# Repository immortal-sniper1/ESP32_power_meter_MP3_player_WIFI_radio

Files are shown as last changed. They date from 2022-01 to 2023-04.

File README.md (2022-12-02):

# PCB_test_project_01
 First ESP32 pcb project, it will have power meters( 24V 3A, 5V 0.5A, and self consumption), uSD card, WIFI/BT and the ability to play back MP3/audio file.     
 Also it will feature a power usage meter. It can also be powered from a 18650 Li ion cell, if the USB is alsoo pluged in the cell will start chargeing.
 The chargeing current is limited by the chargeing IC useing a potenciometer as the input. If the red LED is on then the cell is cahrgeing and if the green
 LED is on then the cell is fully charged.
 NOTE: the voltage levels are set by the ICs and it is : 4.2V as charged state and 3V as discharged.
 If the cel voltage reaches 3V or lower then a circuit will activate and disconect the cell from the system so that it will not overdischarge.
 
 V1 is made with ESP32-MINI and that is super hard to hand assemble so V2+ wil use the VROOM

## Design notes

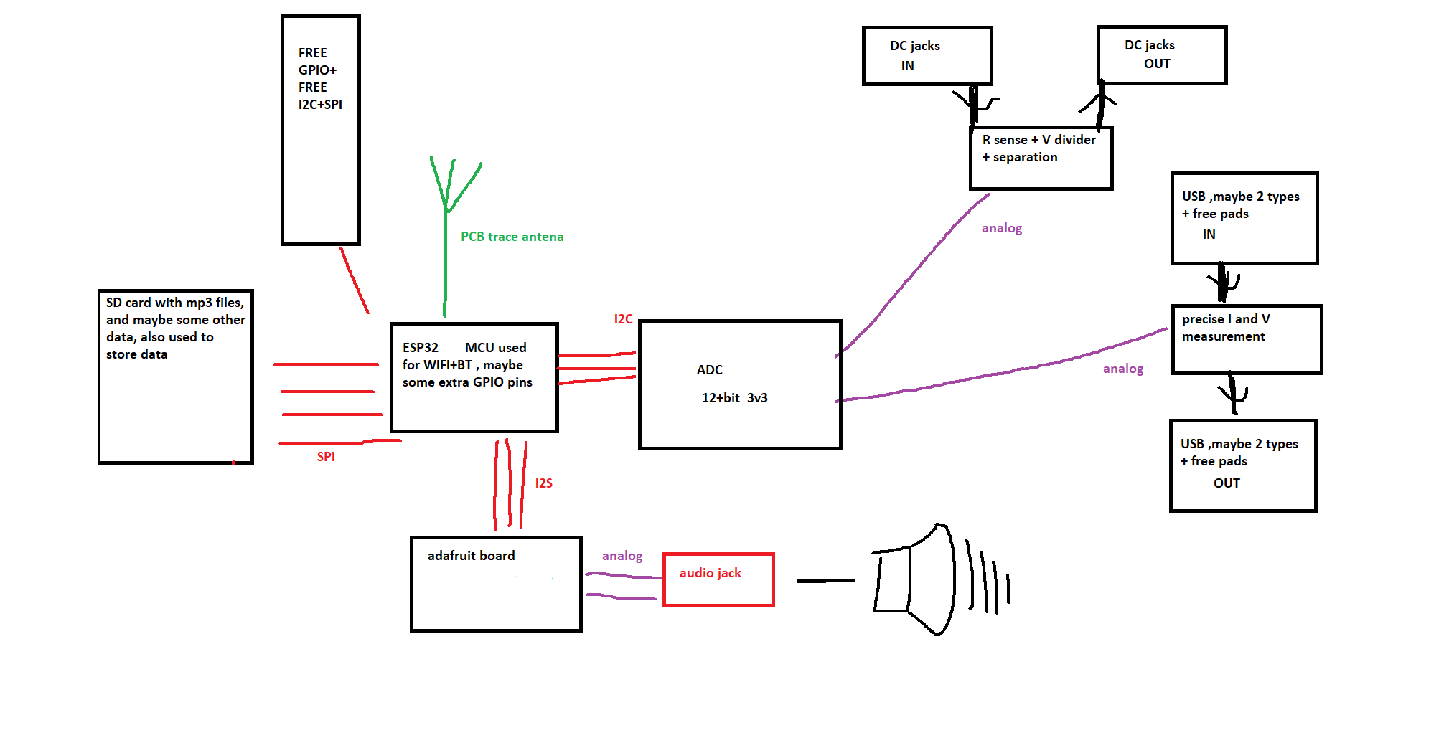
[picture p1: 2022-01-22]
ESP32_power_meter_MP3_player_WIFI_radio_V2/concept.png

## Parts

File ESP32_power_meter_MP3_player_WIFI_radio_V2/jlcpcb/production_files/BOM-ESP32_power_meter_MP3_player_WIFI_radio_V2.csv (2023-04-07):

Comment | Designator | Footprint | LCSC
100n | C13,C14,C15,C18,C21,C30 | C_0603_1608Metric_Pad1.08x0.95mm_HandSolder | C14663
100n | C10,C12,C16,C17,C19,C2,C20,C24,C3,C31,C6,C8 | C_0603_1608Metric_Pad1.08x0.95mm_HandSolder | C1623
1k | R1,R31,R34,R39,R41 | R_0603_1608Metric_Pad0.98x0.95mm_HandSolder | C21190
LED_Small | D5 | LED_0603_1608Metric_Pad1.05x0.95mm_HandSolder | C2286
0 | R49,R50 | R_0603_1608Metric_Pad0.98x0.95mm_HandSolder | C22936
330 | R10,R11,R12 | R_0603_1608Metric_Pad0.98x0.95mm_HandSolder | C23025
4k7 | R9 | R_0603_1608Metric_Pad0.98x0.95mm_HandSolder | C23162
91k | RR1 | R_0805_2012Metric_Pad1.20x1.40mm_HandSolder | C23265
100k | R16,R17,R20,R26,R32,R36 | R_0603_1608Metric_Pad0.98x0.95mm_HandSolder | C25803
10k | R13,R14,R15,R18,R19,R2,R21,R22,R23,R24,R25,R27,R3,R33,R35,R37,R38,R4,R40,R43,R44,R45,R46,R48,R5,R51,R6,R7,R8 | R_0603_1608Metric | C25804
GPIO_RESET | SW1,SW2,SW3 | PTS526SK15SMTR2LFS | C318884
20k | RR2 | R_0805_2012Metric_Pad1.20x1.40mm_HandSolder | C4184
10u | C1,C22,C23,C25,C26,C28,C29,C4,C5,C7,C9 | C_0805_2012Metric | C45783
LM324 | U6 | SOIC-14_3.9x8.7mm_P1.27mm | C71035
Green | D1,D2,D3,D4,D6 | LED_0603_1608Metric_Pad1.05x0.95mm_HandSolder | C72043
SRV05-4 | U5 | SOT-23-6 | C85364
FerriteBead_Small | FB2 | R_0603_1608Metric_Pad0.98x0.95mm_HandSolder
Conn_01x03 | J12 | SCREWTERMINAL-5MM-3
I2C | J16 | PinHeader_1x04_P2.54mm_Vertical
HI1806T600R-10 | FB1 | BEADC4516X185N
APX810S05 | U8 | SOT-23
LM4040DBZ-3 | U1 | SOT-23
Conn_02x10_Odd_Even | J14 | PinHeader_2x10_P2.54mm_Vertical
Conn_01x02 | J10 | TestPoint_2Pads_Pitch5.08mm_Drill1.3mm
DIO6012BCST6 | U9 | SOT-23-6_Handsoldering
22p optional | C27 | C_0603_1608Metric_Pad1.08x0.95mm_HandSolder
ESP32-S3-WROOM-1 | U4 | ESP32-S3-WROOM-1
Conn_01x02 | J13 | PinHeader_1x02_P2.54mm_Vertical
Barrel_Jack_Switch | J5 | DC plug jack 5.5-2.5mm
1.5 A | F1 | Fuse_1812_4532Metric
30m | R29 | R_0805_2012Metric
MEM2051-00-195-00-A | J2 | MEM20510019500A
INA2181A4QDGSRQ1 | IC2 | SOP50P490X110-10N
DS01C-254-S-08BE | S1 | DS01C254S08BE
DMG9933USD-13 | Q2 | SOIC127P600X175-8N
Conn_01x03 | J9 | SCREWTERMINAL-5MM-3
Barrel_Jack_Switch | J7 | BarrelJack_Wuerth_6941xx301002
DNP | C11 | C_0603_1608Metric_Pad1.08x0.95mm_HandSolder
XRA1203IG24TR-F | IC1 | SOP65P640X120-24N
USB_A | J11 | USB_A_Molex_67643_Horizontal
1Meg | R30 | R_0603_1608Metric_Pad0.98x0.95mm_HandSolder
L_Small | L2 | L_1206_3216Metric
USB_A | J3 | USB_A_Molex_67643_Horizontal
5m | R42 | R_0612_1632Metric_Pad1.18x3.40mm_HandSolder
Jumper_3_Open | JP1 | PinHeader_1x03_P2.54mm_Vertical
Adafruit_MAX98357 | U3 | Adafruit MAX98357 I2S Class-D Mono
EG1224 SPDT switch | S2 | EG1224
NRH3012T2R2MN 2,2uH | L1 | NRH3012T220MNV
USB_A | J8 | USB_A_Molex_67643_Horizontal
Conn_01x06 | J4 | PinHeader_1x06_P2.54mm_Vertical
R_Potentiometer | RV1 | Potentiometer_Bourns_3386F_Vertical
STX-3120-5B | J1 | STX31205B
MCP73834T-FCI_UN | IC4 | SOP50P490X110-10N
MCP3208 | U2 | SOIC-16_3.9x9.9mm_P1.27mm
1.5 A | F2 | Fuse_1812_4532Metric
5m | R28 | R_0612_1632Metric_Pad1.18x3.40mm_HandSolder
I2C | J15 | PinHeader_1x04_P2.54mm_Vertical
Conn_01x02 | J6 | TestPoint_2Pads_Pitch5.08mm_Drill1.3mm
AP2112M-3.3TRG1 | IC3 | SOIC127P600X170-8N
D_Shockley | D7 | D_DO-15_P5.08mm_Vertical_AnodeUp
1043 | U7 | 1043

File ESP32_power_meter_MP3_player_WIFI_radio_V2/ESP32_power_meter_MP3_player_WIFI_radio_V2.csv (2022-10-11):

picked | Ref | Qnty | Value | Cmp name | Footprint
 | C1, C3, C8, C26, | 4 | 10u | C_Small | Capacitor_SMD:C_0603_1608Metric_Pad1.08x0.95mm_HandSolder
 | C2, C9, C11, C13, C15, | 5 | 1u | C_Small | Capacitor_SMD:C_0603_1608Metric_Pad1.08x0.95mm_HandSolder
 | C4, C5, C6, C7, C12, C14, C23, | 7 | 100n | C_Small | Capacitor_SMD:C_0603_1608Metric_Pad1.08x0.95mm_HandSolder
 | C10, | 1 | 0.1u | C_Small | Capacitor_SMD:C_0603_1608Metric_Pad1.08x0.95mm_HandSolder
 | C16, | 1 | 4.7u | C_Small | Capacitor_SMD:C_0603_1608Metric_Pad1.08x0.95mm_HandSolder
 | C17, C18, | 2 | 1u | C_Small | Capacitor_SMD:C_0805_2012Metric_Pad1.18x1.45mm_HandSolder
 | C19, | 1 | 22u | C_Small | Capacitor_THT:CP_Radial_D5.0mm_P2.00mm
 | C20, | 1 | 22p optional | C_Small | Capacitor_SMD:C_0603_1608Metric_Pad1.08x0.95mm_HandSolder
 | C21, C22, C24, C25, | 4 | 10u | C_Small | Capacitor_SMD:C_0805_2012Metric
 | D1, D5, D6, D7, D8, D9, | 6 | LED_Small Green | LED_Small | LED_SMD:LED_0603_1608Metric_Pad1.05x0.95mm_HandSolder
 | D2, D3, | 2 | LED_Small | LED_Small | LED_SMD:LED_0603_1608Metric_Pad1.05x0.95mm_HandSolder
 | D4, | 1 | D_Shockley | D_Shockley | Diode_THT:D_DO-15_P5.08mm_Vertical_AnodeUp
 | F1, F2, | 2 | 1.5 A | Fuse | Fuse:Fuse_0603_1608Metric_Pad1.05x0.95mm_HandSolder
 | FB1, | 1 | HI1806T600R-10 | HI1806T600R-10 | SamacSys_Parts:BEADC4516X185N
 | FB2, | 1 | FerriteBead_Small | FerriteBead_Small | Resistor_SMD:R_0402_1005Metric_Pad0.72x0.64mm_HandSolder
 | IC1, | 1 | XRA1203IG24TR-F | XRA1203IG24TR-F | SamacSys_Parts:SOP65P640X120-24N
 | IC2, | 1 | INA2181A4QDGSRQ1 | INA2181A4QDGSRQ1 | SOP50P490X110-10N
 | IC3, | 1 | MCP73834T-FCI_UN | MCP73834T-FCI_UN | SamacSys_Parts:SOP50P490X110-10N
 | IC4, | 1 | AP2112M-3.3TRG1 | AP2112M-3.3TRG1 | SamacSys_Parts:SOIC127P600X170-8N
 | J1, | 1 | STX-3120-5B | STX-3120-5B | SamacSys_Parts:STX31205B
 | J2, | 1 | SS-52100-001 | SS-52100-001 | SamacSys_Parts:SS52100001
 | J3, | 1 | MEM2051-00-195-00-A | MEM2051-00-195-00-A | SamacSys_Parts:MEM20510019500A
 | J4, | 1 | Barrel_Jack_Switch | Barrel_Jack_Switch | Z_mycustom_footprint_lib:DC plug jack 5.5-2.5mm
 | J5, | 1 | Barrel_Jack_Switch | Barrel_Jack_Switch | Connector_BarrelJack:BarrelJack_Wuerth_6941xx301002
 | J6, J7, | 2 | Conn_01x03 | Conn_01x03 | Connectors:SCREWTERMINAL-5MM-3
 | J8, | 1 | Conn_01x06 | Conn_01x06 | Connector_PinHeader_2.54mm:PinHeader_1x06_P2.54mm_Vertical
 | J9, | 1 | USB_A | USB_A | Connector_USB:USB_A_Molex_67643_Horizontal
 | J10, | 1 | 10033527-N3112MLF | 10033527-N3112MLF | SamacSys_Parts:10033527N3112MLF
 | J11, J12, | 2 | Conn_01x02 | Conn_01x02 | TestPoint:TestPoint_2Pads_Pitch5.08mm_Drill1.3mm
 | J13, | 1 | Conn_01x02 | Conn_01x02 | Connector_PinHeader_2.54mm:PinHeader_1x02_P2.54mm_Vertical
 | JP1, | 1 | Jumper_2_Bridged | Jumper_2_Bridged | Jumper:SolderJumper-2_P1.3mm_Bridged_RoundedPad1.0x1.5mm
 | JP2, | 1 | Jumper_3_Open | Jumper_3_Open | Connector_PinHeader_2.54mm:PinHeader_1x03_P2.54mm_Vertical
 | L1, | 1 | NRH3012T2R2MN 2,2uH | NRH3012T2R2MN | SamacSys_Parts:NRH3012T220MNV
 | Q1, | 1 | DMG9933USD-13 | DMG9933USD-13 | SamacSys_Parts:SOIC127P600X175-8N
 | R1, R24, R25, | 3 | 1k | R_Small | Resistor_SMD:R_0603_1608Metric_Pad0.98x0.95mm_HandSolder
 | R2, R4, R5, R6, R7, R8, R9, R10, R11, R12, R13, R14, R15, R16, R17, R18, R19, R21, R22, R23, R28, R33, R34, R38, R39, R40, | 26 | 10k | R | Resistor_SMD:R_0603_1608Metric_Pad0.98x0.95mm_HandSolder
 | R3, | 1 | 20k | R | Resistor_SMD:R_0603_1608Metric_Pad0.98x0.95mm_HandSolder
 | R20, | 1 | 4.7k | R | Resistor_SMD:R_0805_2012Metric
 | R26, R27, R29, | 3 | 100k | R_Small | Resistor_SMD:R_0603_1608Metric_Pad0.98x0.95mm_HandSolder
 | R30, R44, R45, R46, R47, | 5 | 330 | R | Resistor_SMD:R_0603_1608Metric_Pad0.98x0.95mm_HandSolder
 | R31, R41, | 2 | 5m | R | Resistor_SMD:R_0612_1632Metric_Pad1.18x3.40mm_HandSolder
 | R32, R42, R43, | 3 | 1Meg | R_Small | Resistor_SMD:R_0603_1608Metric_Pad0.98x0.95mm_HandSolder
 | R35, | 1 | 30m | R | Resistor_SMD:R_0402_1005Metric_Pad0.72x0.64mm_HandSolder
 | R36, R37, | 2 | 470 | R_Small | Resistor_SMD:R_0603_1608Metric_Pad0.98x0.95mm_HandSolder
 | RR1, | 1 | 91k | R_Small | Resistor_SMD:R_0805_2012Metric_Pad1.20x1.40mm_HandSolder
 | RR2, | 1 | 20k | R_Small | Resistor_SMD:R_0805_2012Metric_Pad1.20x1.40mm_HandSolder
 | RV1, | 1 | R_Potentiometer | R_Potentiometer | Potentiometer_THT:Potentiometer_Bourns_3386F_Vertical
 | S1, S2, | 2 | DS01C-254-S-08BE | DS01C-254-S-08BE | SamacSys_Parts:DS01C254S08BE
 | S3, | 1 | EG1224 SPDT switch | EG1224 | SamacSys_Parts:EG1224
 | SW1, | 1 | SW_SPST | SW_SPST | SamacSys_Parts:PTS526SM15SMTR2LFS
 | TP1, TP2, TP3, | 3 | TestPoint | TestPoint | TestPoint:TestPoint_Pad_1.0x1.0mm
 | U1, | 1 | ESP32-C3-MINI-1 | ESP32-C3-MINI-1 | Espressif:ESP32-C3-MINI-1_Hand-Soldering
 | U2, | 1 | LM4040DBZ-3 | LM4040DBZ-3 | Package_TO_SOT_SMD:SOT-23
 | U3, | 1 | MCP3208 | MCP3208 | Package_SO:SOIC-16_3.9x9.9mm_P1.27mm
 | U4, | 1 | Adafruit_MAX98357 | Adafruit_MAX98357 | Z_mycustom_footprint_lib:Adafruit MAX98357 I2S Class-D Mono
 | U5, | 1 | D1213A-02SM | D1213A-02SM | Package_TO_SOT_SMD:SOT-23-5
 | U6, | 1 | LM324A | LM324A | Package_SO:SOIC-14_3.9x8.7mm_P1.27mm
 | U7, | 1 | 1043 | 1043 | SamacSys_Parts:1043
 | U8, | 1 | APX810S05 | APX810S05 | Package_TO_SOT_SMD:SOT-23
 | U10, | 1 | DIO6012BCST6 | DIO6012BCST6 | Package_TO_SOT_SMD:SOT-23-6_Handsoldering

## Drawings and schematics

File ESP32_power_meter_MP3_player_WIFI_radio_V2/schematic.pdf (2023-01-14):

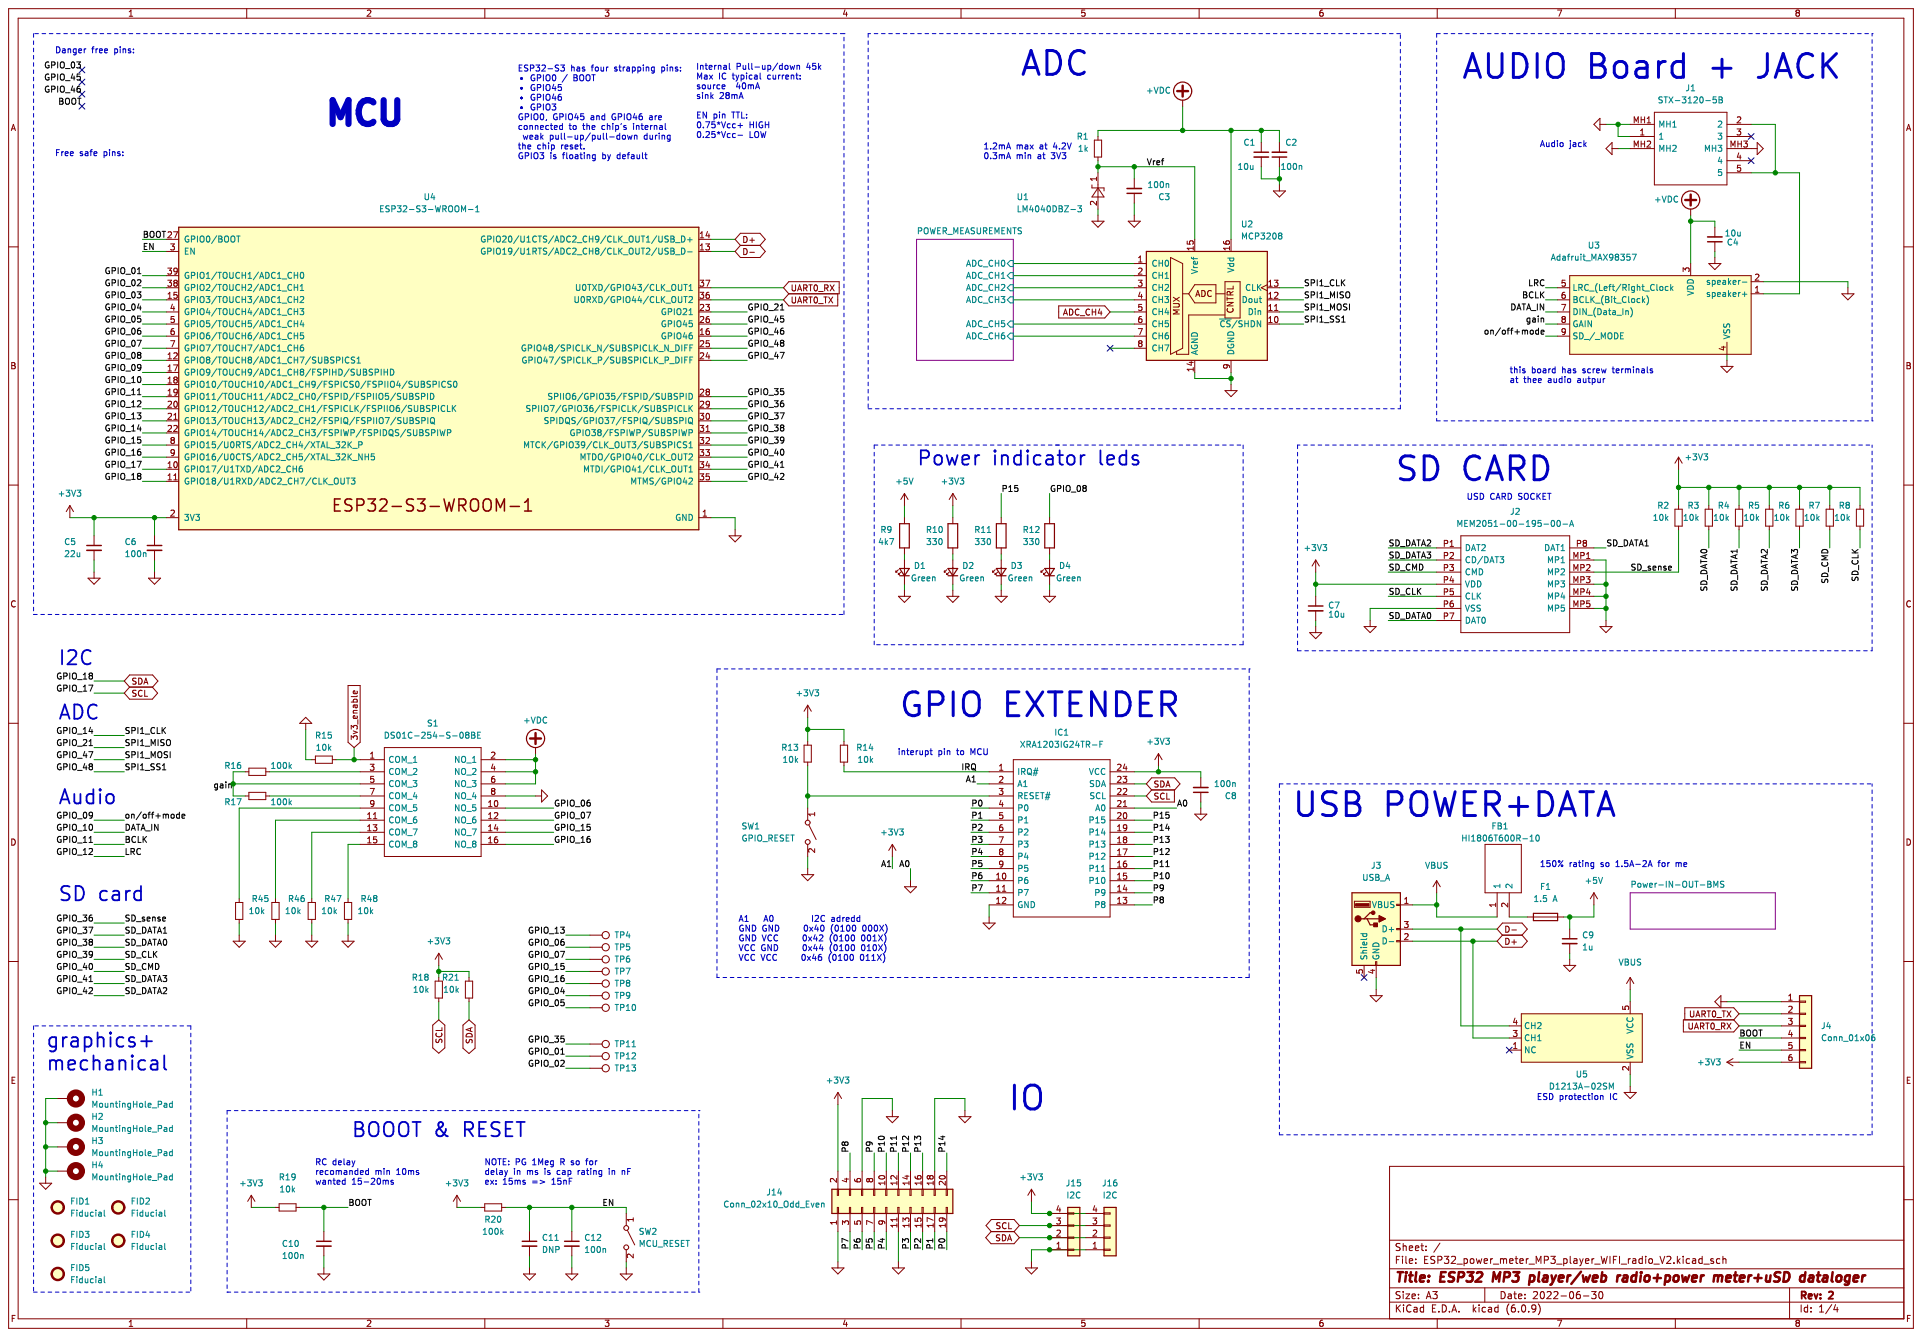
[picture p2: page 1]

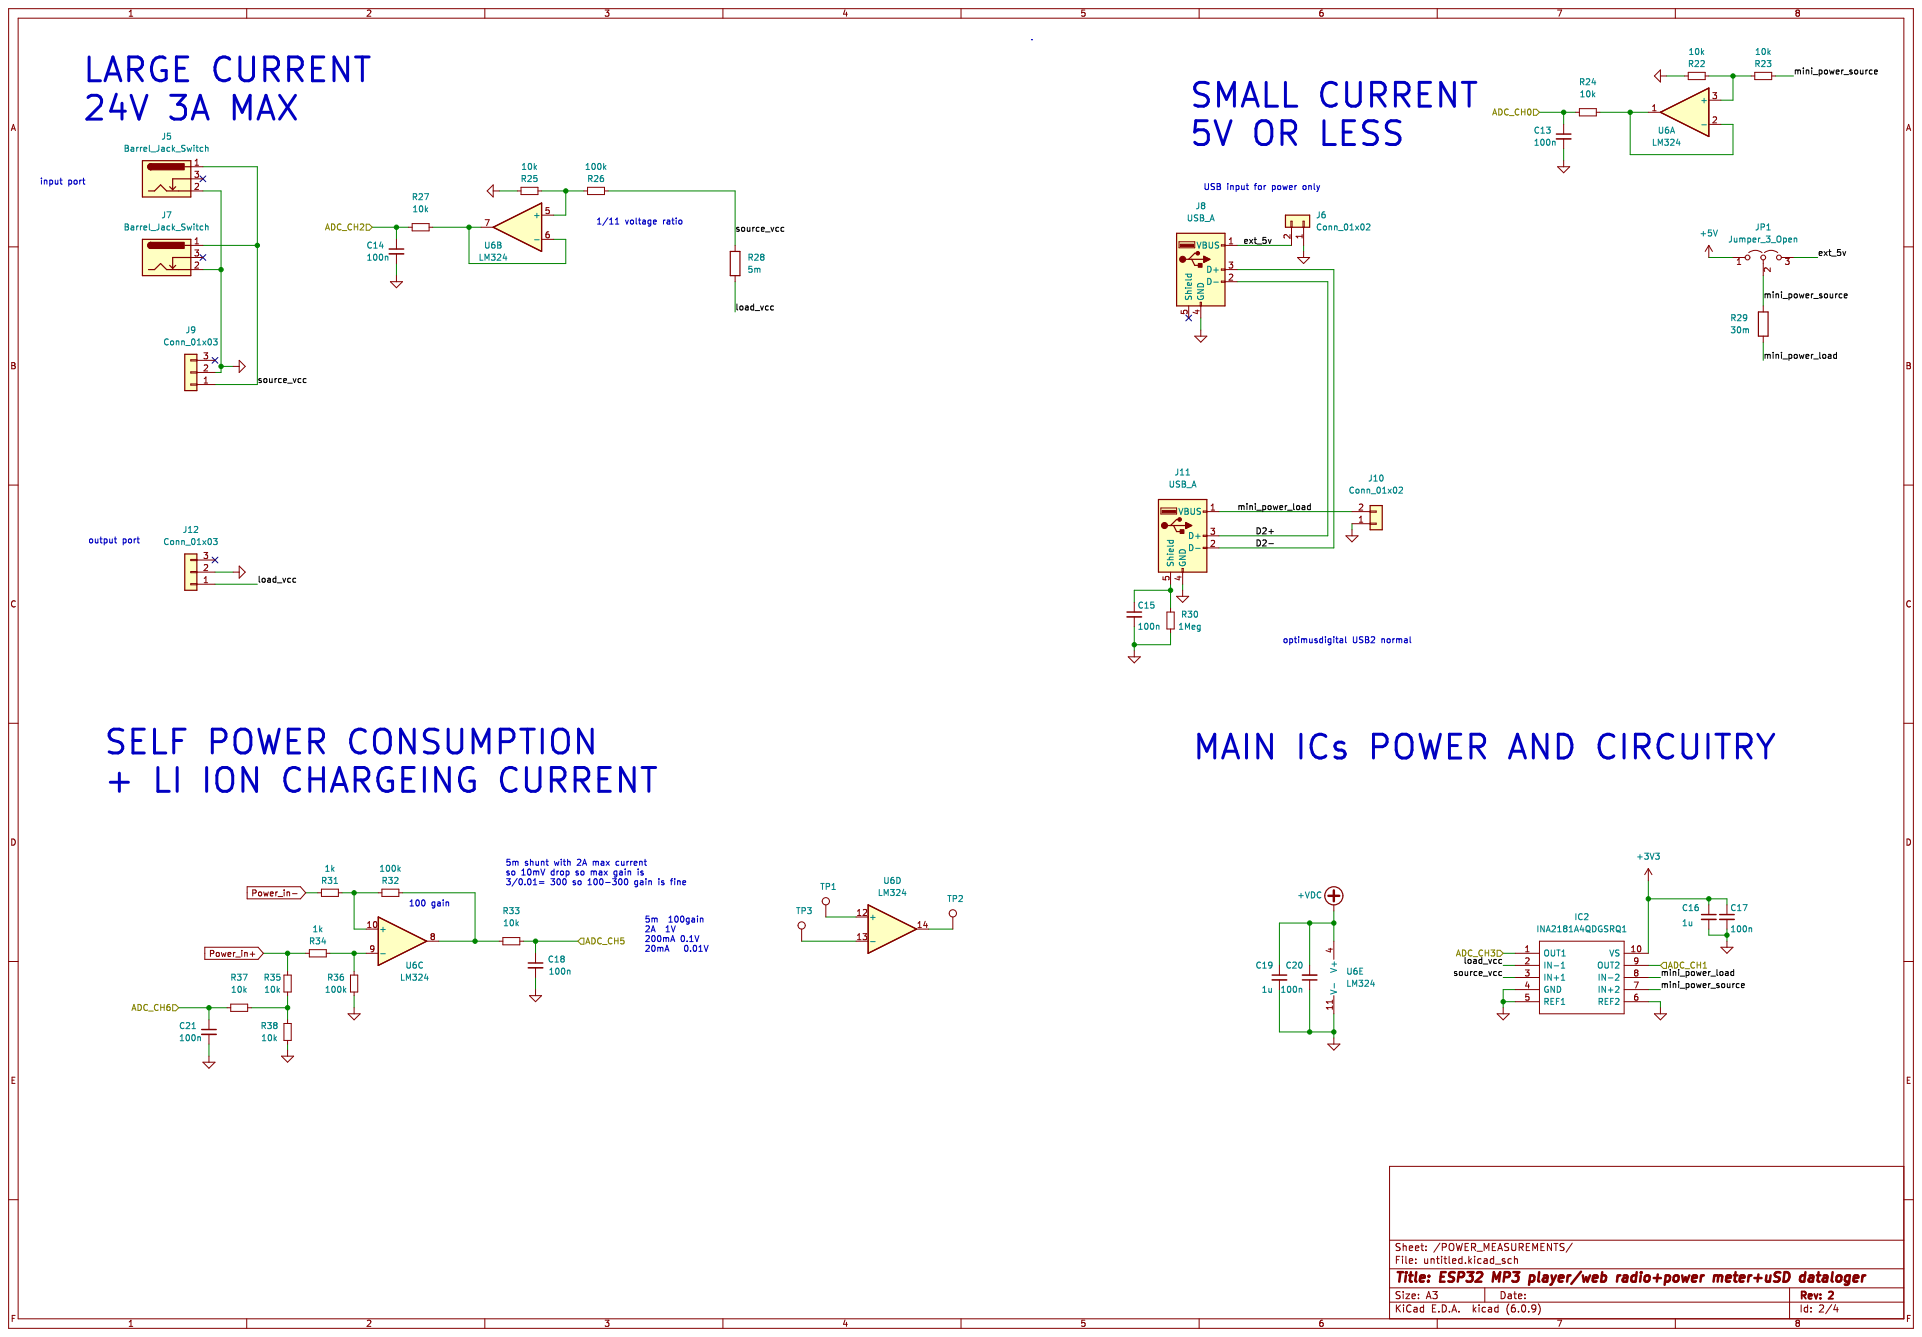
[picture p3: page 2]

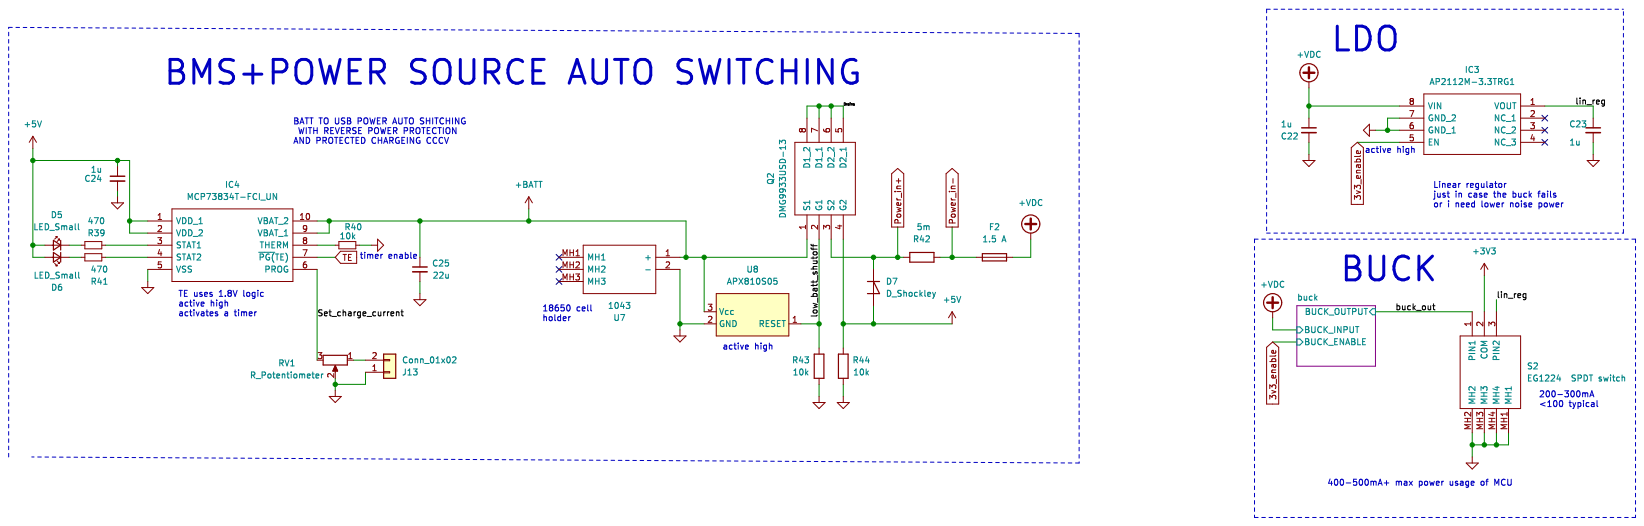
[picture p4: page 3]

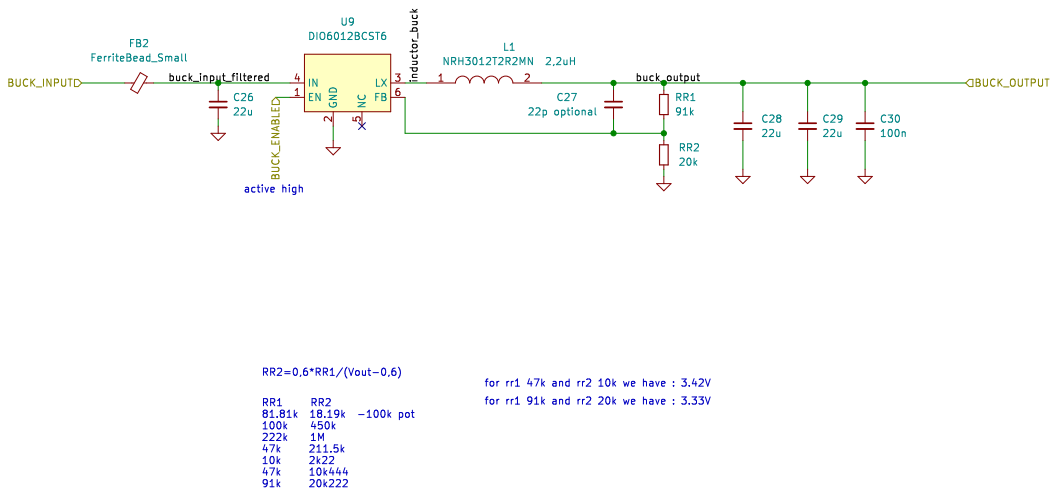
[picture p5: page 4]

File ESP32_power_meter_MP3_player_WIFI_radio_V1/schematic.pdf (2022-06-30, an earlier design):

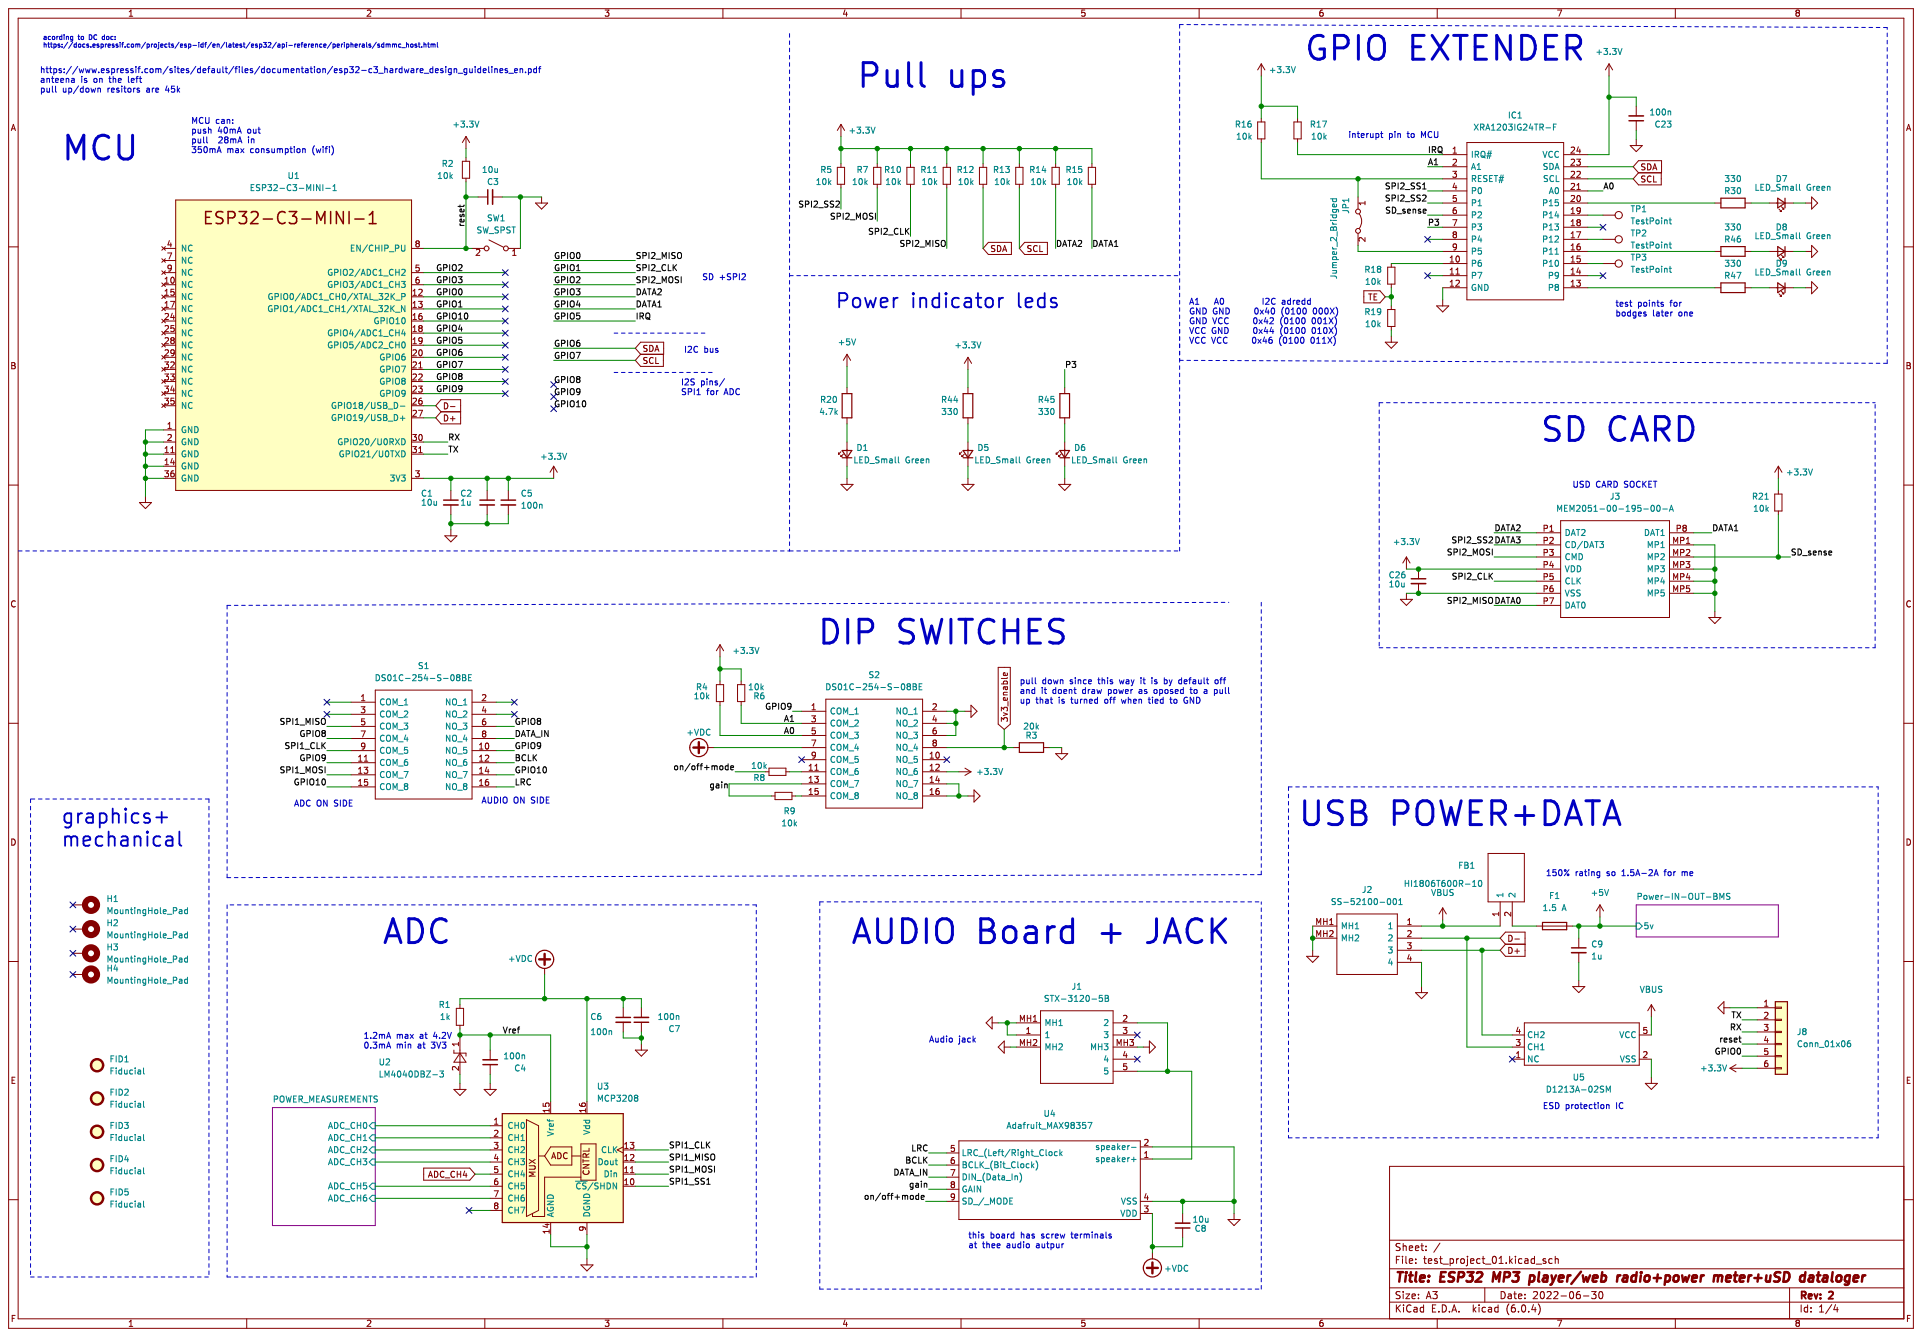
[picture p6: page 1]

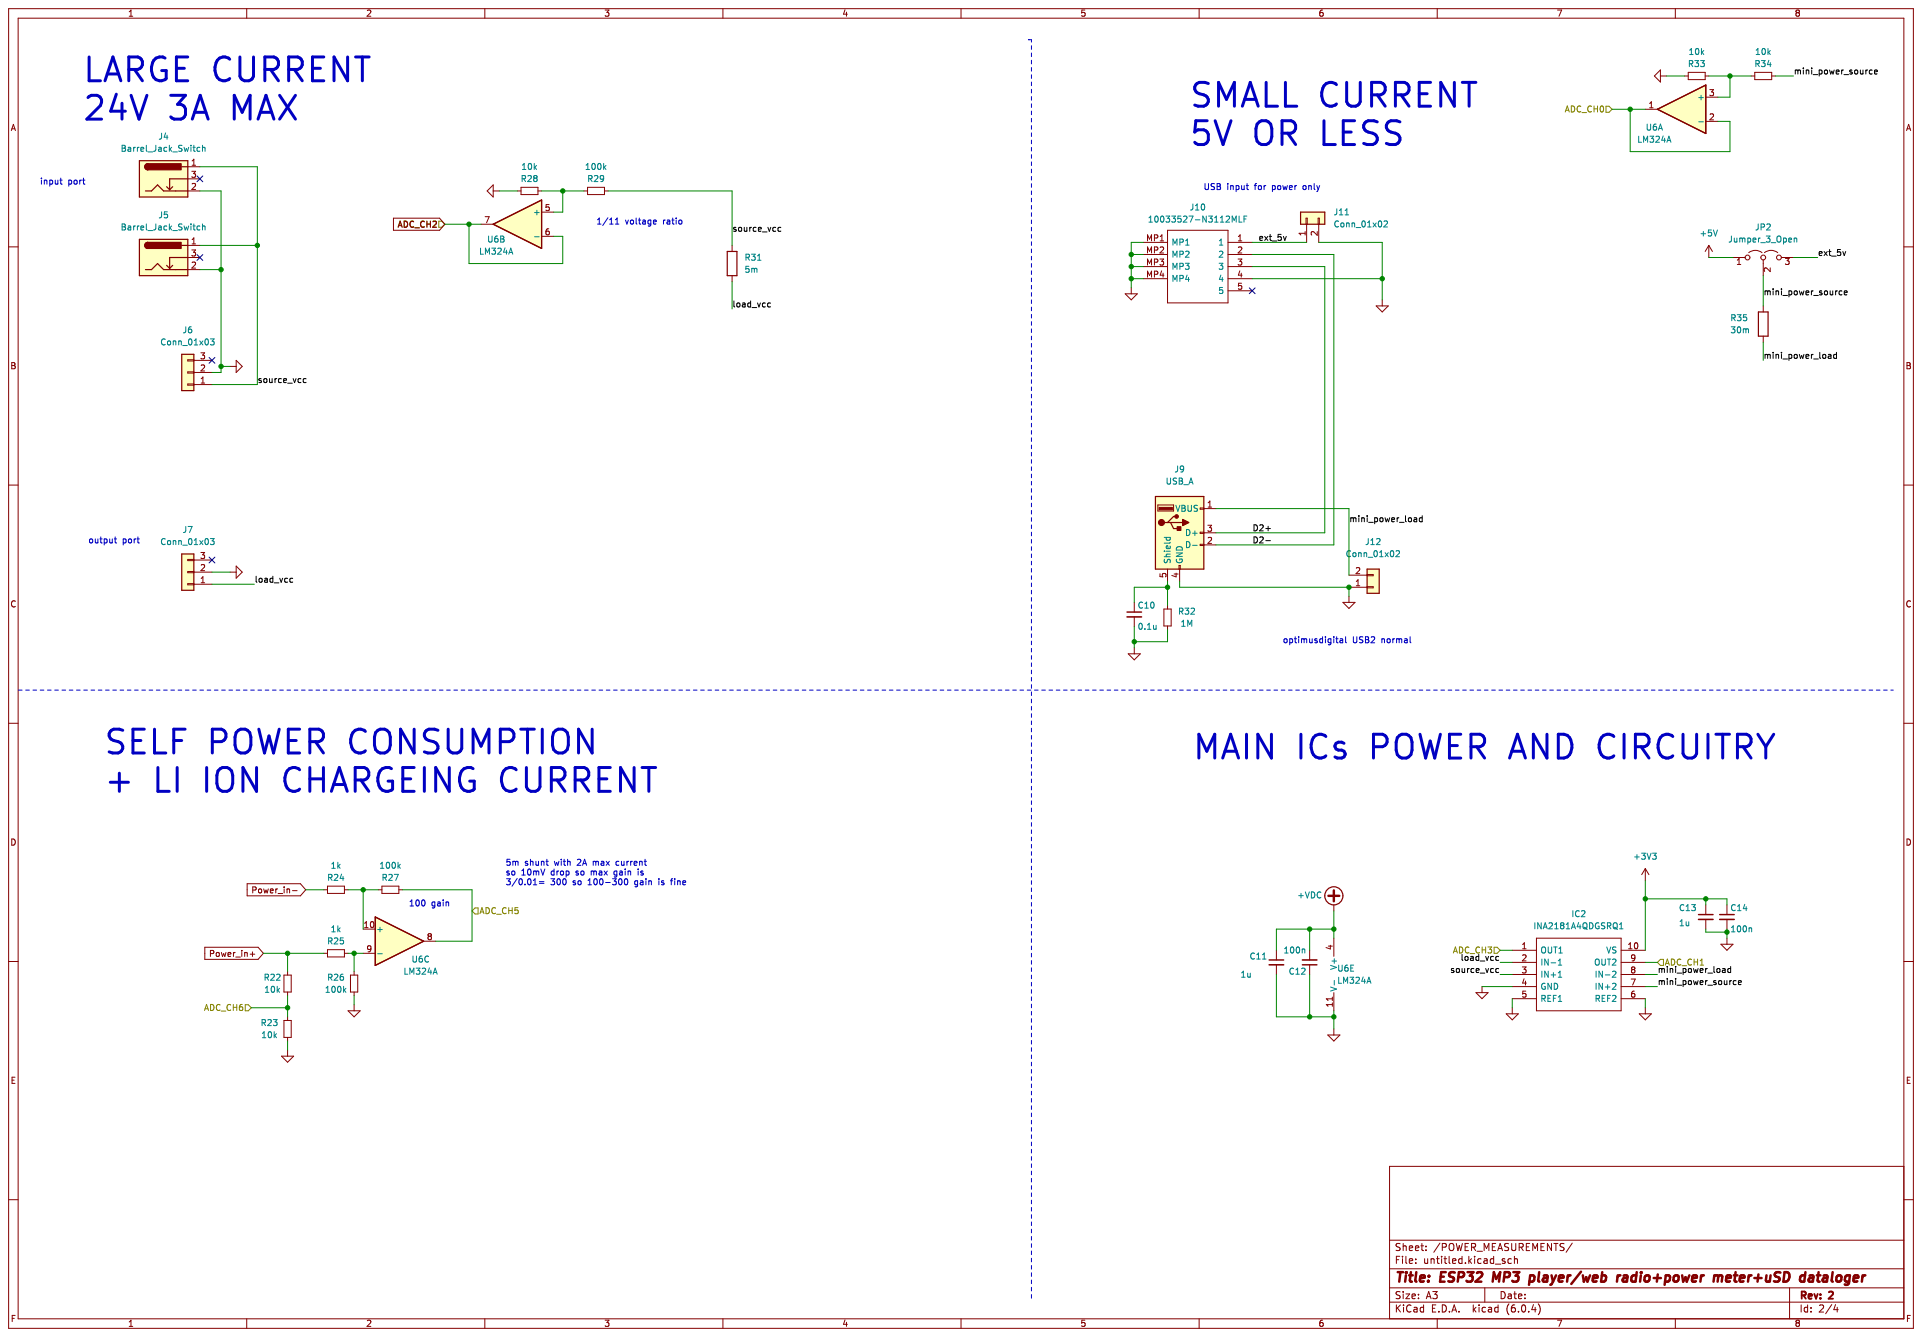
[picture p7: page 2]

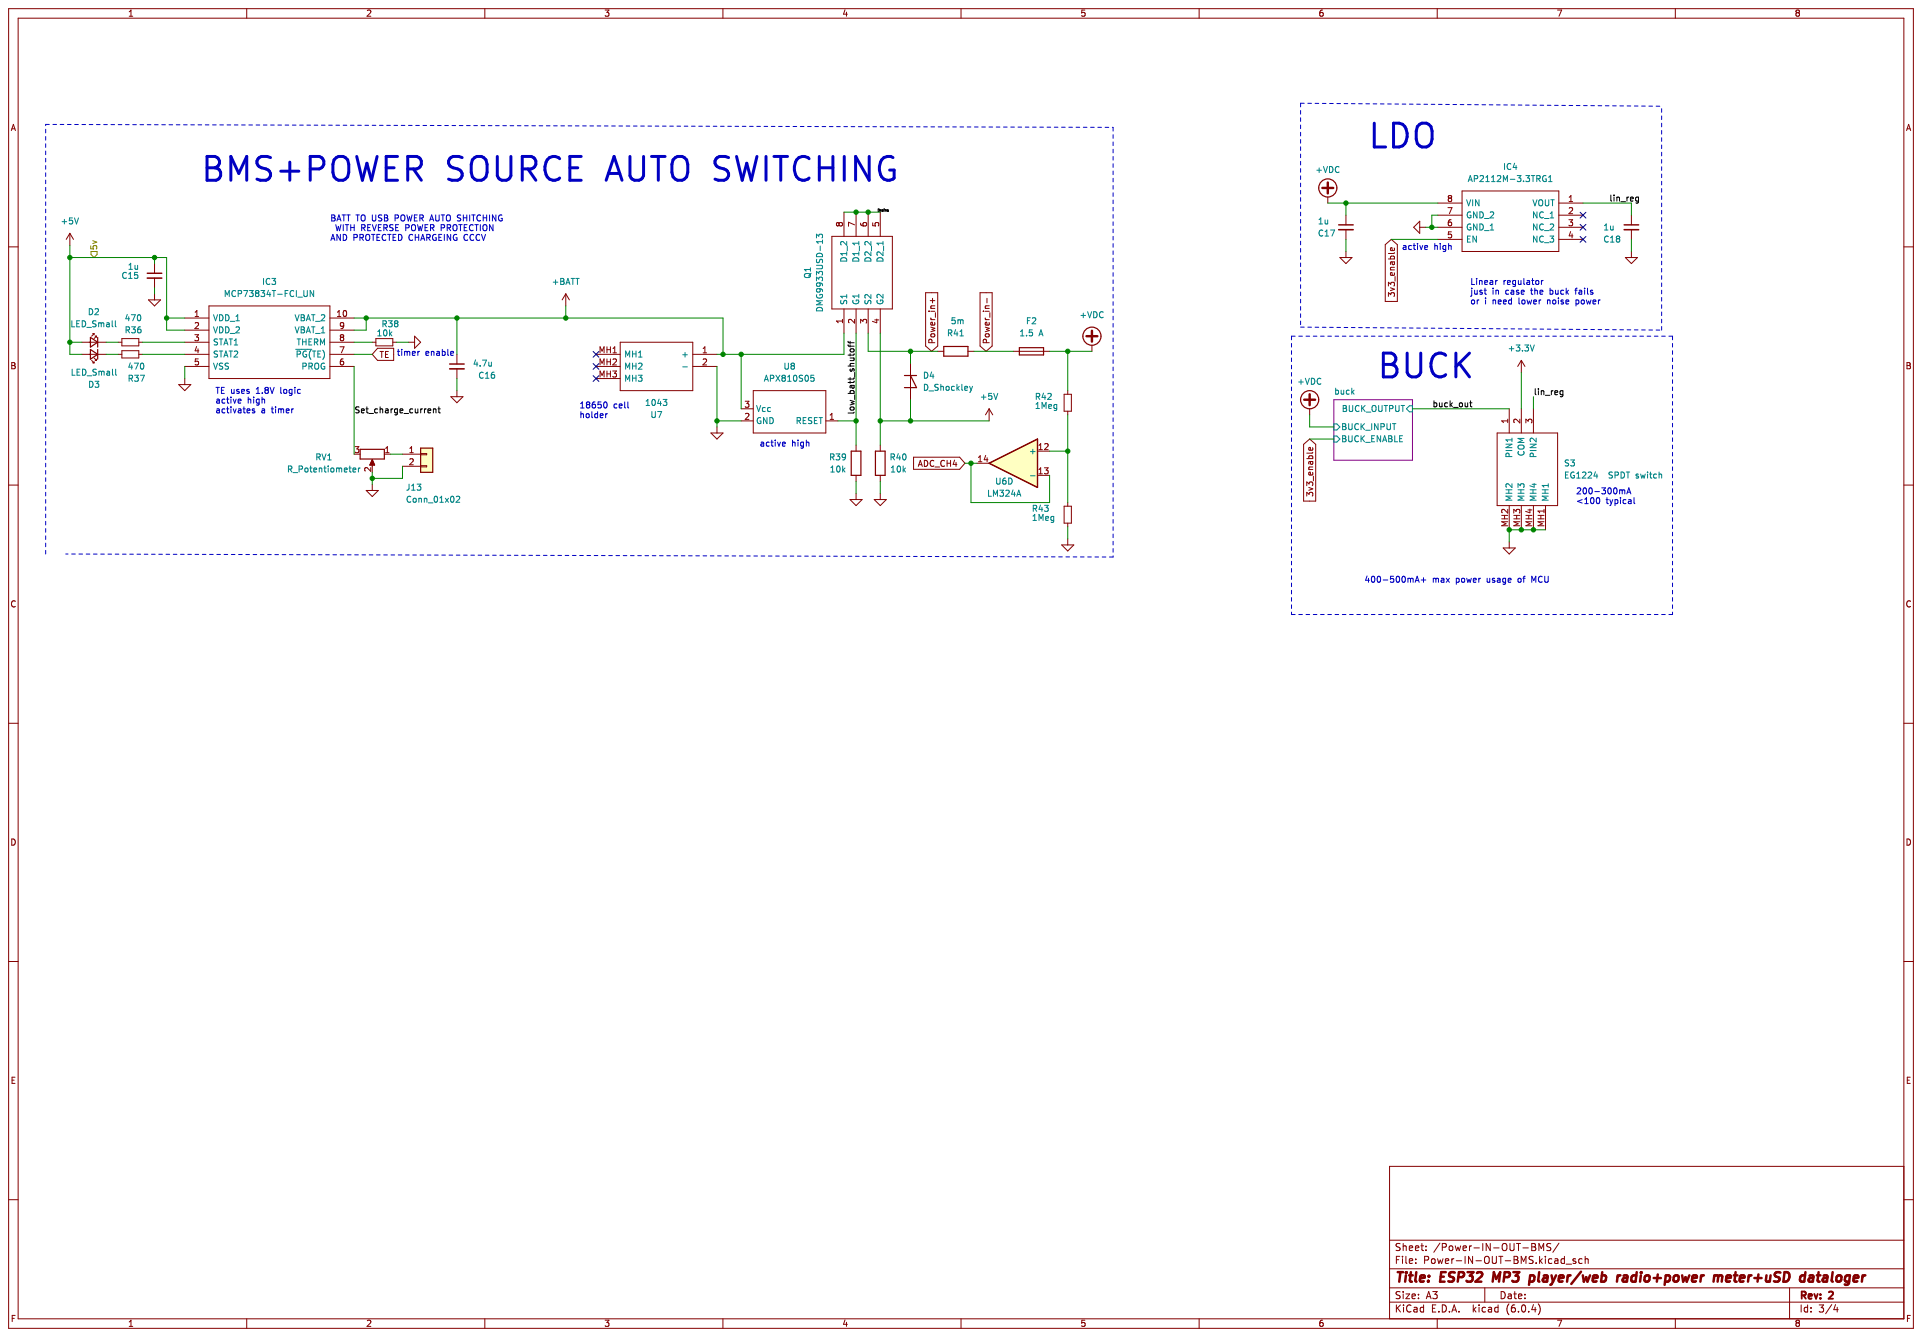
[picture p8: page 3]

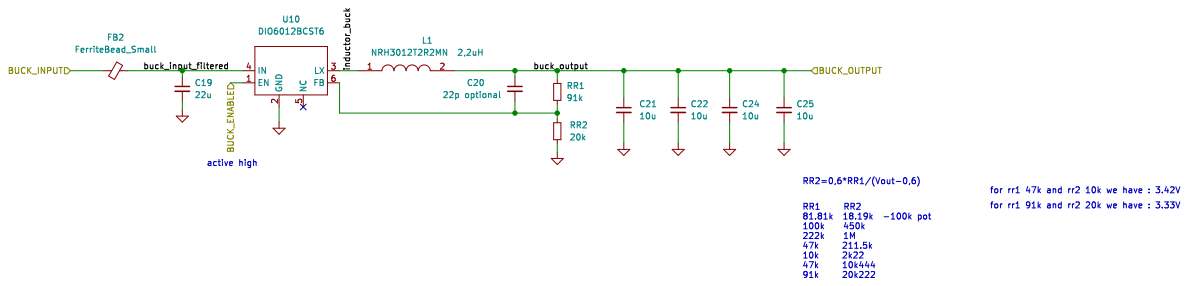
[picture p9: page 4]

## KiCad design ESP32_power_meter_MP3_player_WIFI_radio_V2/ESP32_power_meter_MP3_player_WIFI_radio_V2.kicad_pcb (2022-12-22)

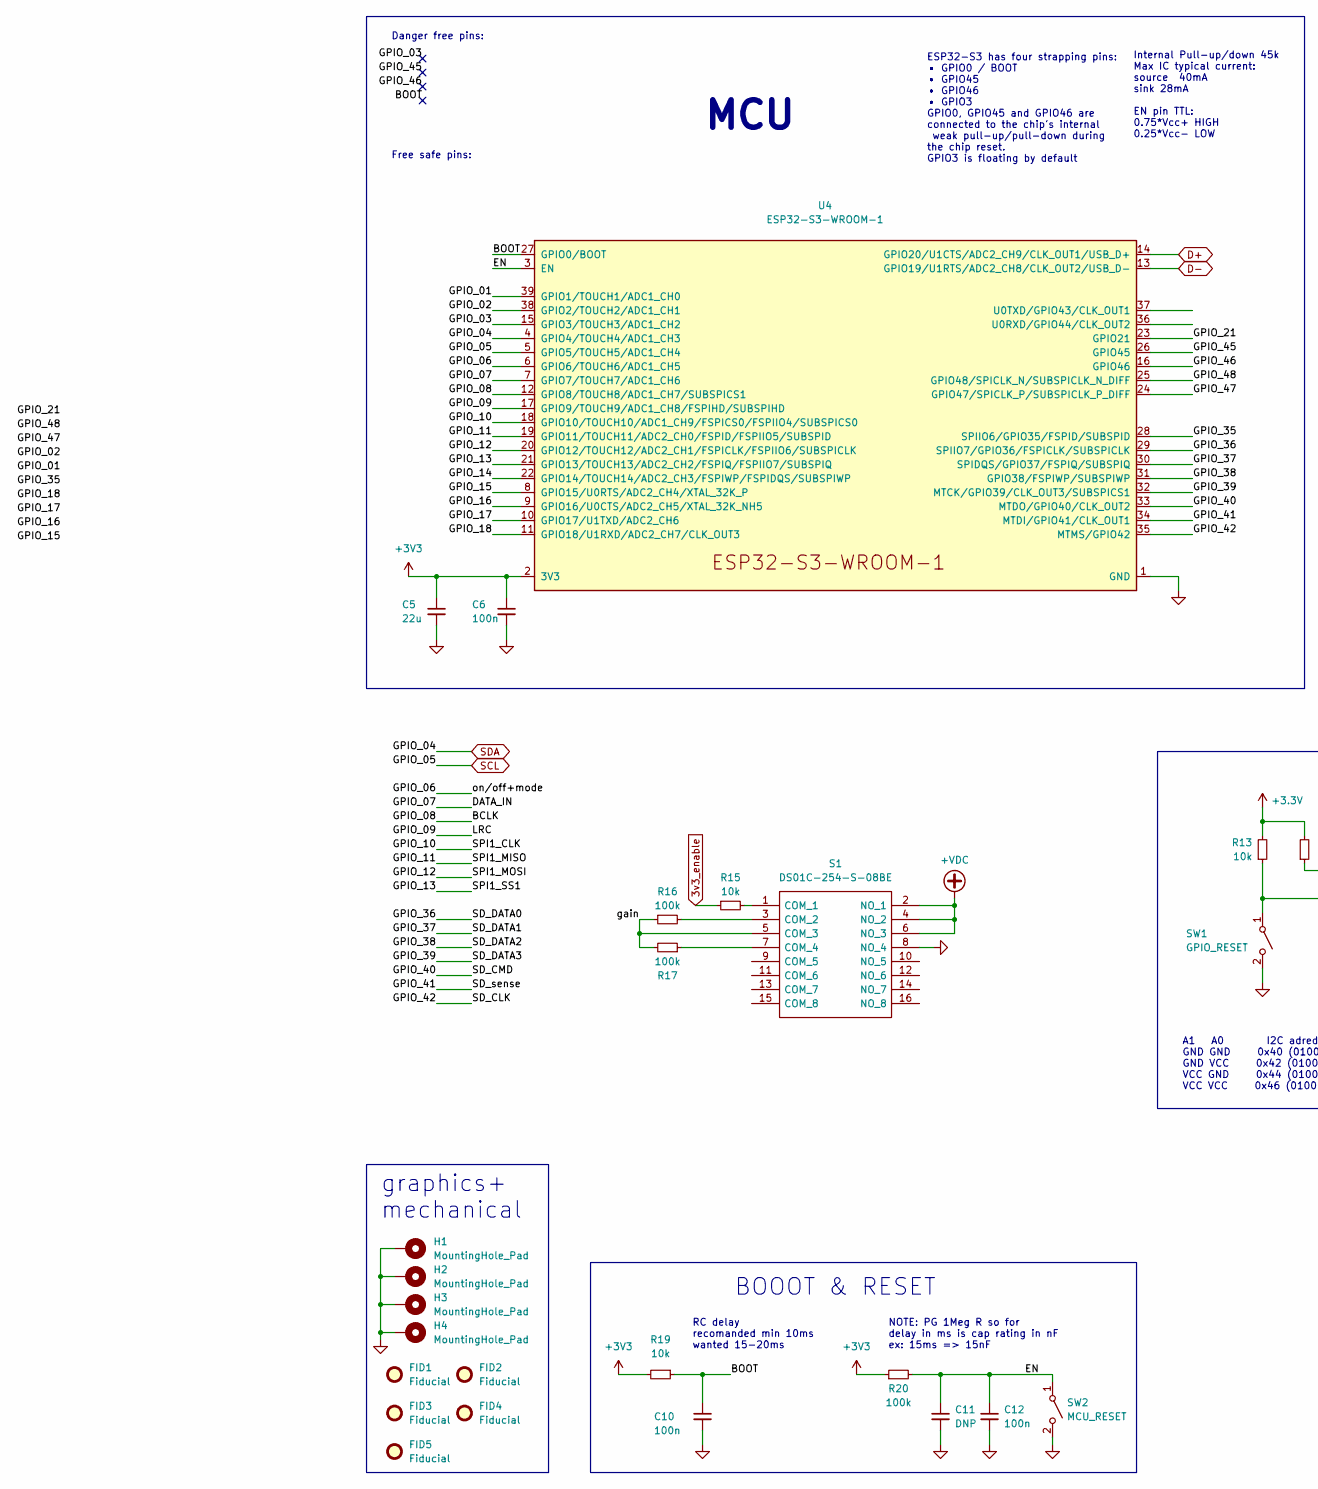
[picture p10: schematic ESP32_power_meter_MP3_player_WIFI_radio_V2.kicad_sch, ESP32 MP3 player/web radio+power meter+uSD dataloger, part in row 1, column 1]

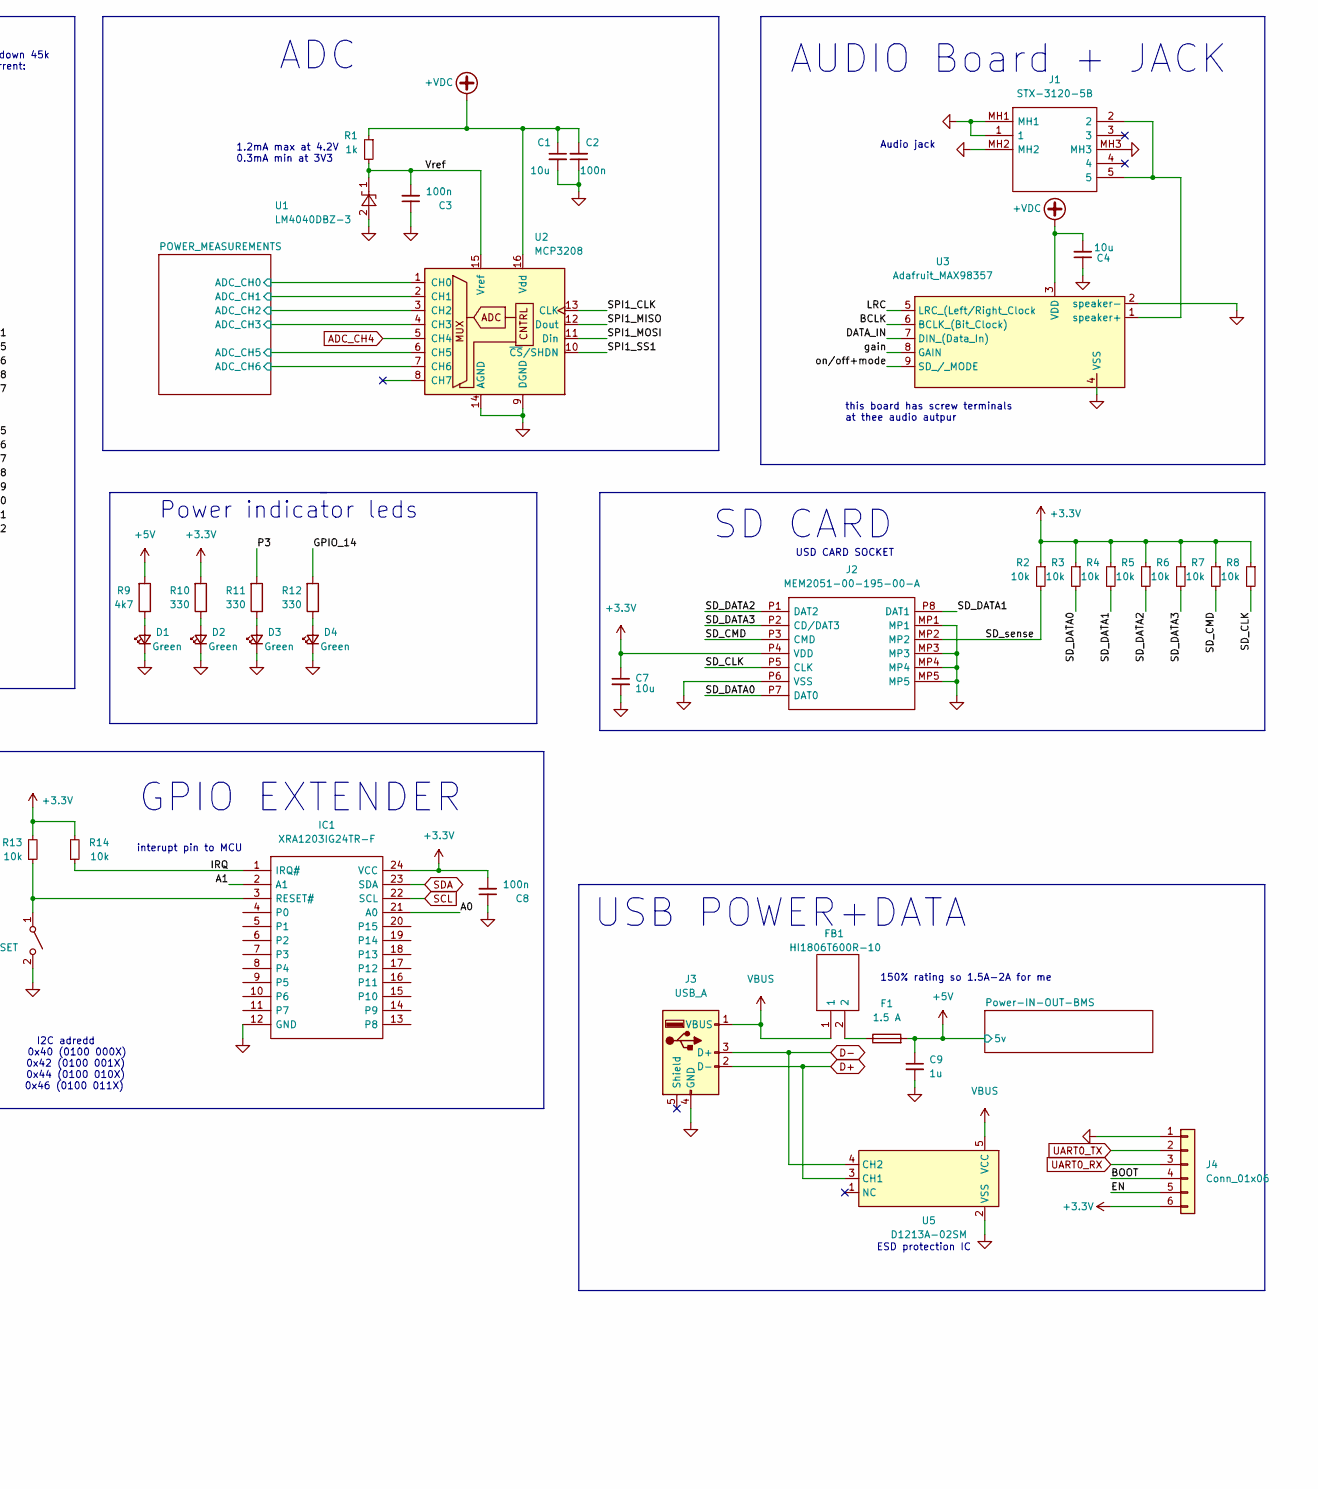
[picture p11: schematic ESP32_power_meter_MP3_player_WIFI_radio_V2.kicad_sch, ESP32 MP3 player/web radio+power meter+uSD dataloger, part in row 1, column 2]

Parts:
C1, C4, C7: 10u; C_0805_2012Metric
C2, C3, C6, C8, C10, C12: 100n; C_0603_1608Metric_Pad1.08x0.95mm_HandSolder
C5: 22u; C_0805_2012Metric_Pad1.18x1.45mm_HandSolder
C9: 1u; C_0603_1608Metric_Pad1.08x0.95mm_HandSolder
C11: DNP; C_0603_1608Metric_Pad1.08x0.95mm_HandSolder
D1, D2, D3, D4: Green; LED_0603_1608Metric_Pad1.05x0.95mm_HandSolder
F1: 1.5 A; Fuse_1812_4532Metric
FB1: HI1806T600R-10; BEADC4516X185N; Mouser Part Number 875-HI1806T600R-10
FID1: Fiducial; Fiducial_0.5mm_Mask1mm
FID2: Fiducial; KiCad-Logo2_6mm_SilkScreen
FID3: Fiducial; Polarity_Center_Positive_6mm_SilkScreen
FID4: Fiducial; WEEE-Logo_5.6x8mm_SilkScreen
FID5: Fiducial; OSHW-Logo_5.7x6mm_SilkScreen
H1, H2, H3, H4: MountingHole_Pad; MountingHole_3.2mm_M3
IC1: XRA1203IG24TR-F; SOP65P640X120-24N; Mouser Part Number 701-XRA1203IG24TR-F
J1: STX-3120-5B; STX31205B; Mouser Part Number 806-STX-3120-5B
J2: MEM2051-00-195-00-A; MEM20510019500A; Mouser Part Number 640-MEM20510019500A
J3: USB_A; USB_A_Molex_67643_Horizontal
J4: Conn_01x06; PinHeader_1x06_P2.54mm_Vertical
R1: 1k; R_0603_1608Metric_Pad0.98x0.95mm_HandSolder
R2, R3, R4, R5, R6, R7, R8, R13, R14, R15, R19: 10k; R_0603_1608Metric_Pad0.98x0.95mm_HandSolder
R9: 4k7; R_0603_1608Metric_Pad0.98x0.95mm_HandSolder
R10, R11, R12: 330; R_0603_1608Metric_Pad0.98x0.95mm_HandSolder
R16, R17, R20: 100k; R_0603_1608Metric_Pad0.98x0.95mm_HandSolder
S1: DS01C-254-S-08BE; DS01C254S08BE; Mouser Part Number 490-DS01C-254-S-08BE
SW1: GPIO_RESET; PTS526SK15SMTR2LFS
SW2: MCU_RESET; PTS526SK15SMTR2LFS
U1: LM4040DBZ-3; SOT-23
U2: MCP3208; SOIC-16_3.9x9.9mm_P1.27mm
U3: Adafruit_MAX98357; Adafruit MAX98357 I2S Class-D Mono
U4: ESP32-S3-WROOM-1
U5: D1213A-02SM; SOT-23-5_HandSoldering

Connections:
3v3_enable: R15.1; also elsewhere on the board
+3.3V: C7.1, C8.2, IC1.24 (VCC), J2.P4 (VDD), J4.6, R2.1, R3.1, R4.1, R5.1, R6.1, R7.1, R8.1, R10.2, R13.2, R14.2; also elsewhere on the board
+3V3: C5.1, C6.1, R19.2, R20.1, U4.2 (3V3); also elsewhere on the board
+5V: C9.1, F1.2, R9.2; also elsewhere on the board
+VDC: C1.1, C2.2, C4.2, R1.1, S1.2 (NO_1), S1.4 (NO_2), S1.6 (NO_3), U2.16 (Vdd), U3.3 (VDD); also elsewhere on the board
/A0: IC1.21 (A0)
/A1: IC1.2 (A1)
/BCLK: U3.6 (BCLK_(Bit_Clock)), U4.12 (GPIO8/TOUCH8/ADC1_CH7/SUBSPICS1)
/BOOT: C10.1, J4.4, R19.1, U4.27 (GPIO0/BOOT)
/DATA_IN: U3.7 (DIN_(Data_In)), U4.7 (GPIO7/TOUCH7/ADC1_CH6)
/EN: C11.1, C12.1, J4.5, R20.2, SW2.1 (A), U4.3 (EN)
/GPIO_01: U4.39 (GPIO1/TOUCH1/ADC1_CH0)
/GPIO_02: U4.38 (GPIO2/TOUCH2/ADC1_CH1)
/GPIO_03: U4.15 (GPIO3/TOUCH3/ADC1_CH2)
/GPIO_06: U3.9 (SD_/_MODE), U4.6 (GPIO6/TOUCH6/ADC1_CH5)
/GPIO_09: U3.5 (LRC_(Left/Right_Clock), U4.17 (GPIO9/TOUCH9/ADC1_CH8/FSPIHD/SUBSPIHD)
/GPIO_10: U2.13 (CLK), U4.18 (GPIO10/TOUCH10/ADC1_CH9/FSPICS0/FSPIIO4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)
/GPIO_11: U2.12 (Dout), U4.19 (GPIO11/TOUCH11/ADC2_CH0/FSPID/FSPIIO5/S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)
/GPIO_12: U2.11 (Din), U4.20 (GPIO12/TOUCH12/ADC2_CH1/FSPICLK/FSPIIO6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)
/GPIO_13: U2.10 (~CS/SHDN), U4.21 (GPIO13/TOUCH13/ADC2_CH2/FSPIQ/FSPIIO7/S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)
/GPIO_14: R12.2, U4.22 (GPIO14/TOUCH14/ADC2_CH3/FSPIWP/FSPIDQS/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)
/GPIO_15: U4.8 (GPIO15/U0RTS/ADC2_CH4/XTAL_32K_P)
/GPIO_16: U4.9 (GPIO16/U0CTS/ADC2_CH5/XTAL_32K_NH5)
/GPIO_17: U4.10 (GPIO17/U1TXD/ADC2_CH6)
/GPIO_18: U4.11 (GPIO18/U1RXD/ADC2_CH7/CLK_OUT3)
/GPIO_21: U4.23 (GPIO21)
/GPIO_35: U4.28 (SPIIO6/GPIO35/FSPID/SUBSPID)
/GPIO_36: J2.P7 (DAT0), R3.2, U4.29 (SPIIO7/GPIO36/FSPICLK/SUBSPICLK)
/GPIO_37: J2.P8 (DAT1), R4.2, U4.30 (SPIDQS/GPIO37/FSPIQ/SUBSPIQ)
/GPIO_38: J2.P1 (DAT2), R5.2, U4.31 (GPIO38/FSPIWP/SUBSPIWP)
/GPIO_39: J2.P2 (CD/DAT3), R6.2, U4.32 (MTCK/GPIO39/CLK_OUT3/SUBSPICS1)
/GPIO_40: J2.P3 (CMD), R7.2, U4.33 (MTDO/GPIO40/CLK_OUT2)
/GPIO_41: J2.MP2, R2.2, U4.34 (MTDI/GPIO41/CLK_OUT1)
/GPIO_42: J2.P5 (CLK), R8.2, U4.35 (MTMS/GPIO42)
/GPIO_45: U4.26 (GPIO45)
/GPIO_46: U4.16 (GPIO46)
/GPIO_47: U4.24 (GPIO47/SPICLK_P/SUBSPICLK_P_DIFF)
/GPIO_48: U4.25 (GPIO48/SPICLK_N/SUBSPICLK_N_DIFF)
/IRQ: IC1.1 (IRQ#), R14.1
/P3: R11.2
/POWER_MEASUREMENTS/ADC_CH0: U2.1 (CH0); also elsewhere on the board
/POWER_MEASUREMENTS/ADC_CH1: U2.2 (CH1); also elsewhere on the board
/POWER_MEASUREMENTS/ADC_CH2: U2.3 (CH2); also elsewhere on the board
/POWER_MEASUREMENTS/ADC_CH3: U2.4 (CH3); also elsewhere on the board
/POWER_MEASUREMENTS/ADC_CH5: U2.6 (CH5); also elsewhere on the board
/POWER_MEASUREMENTS/ADC_CH6: U2.7 (CH6); also elsewhere on the board
/Vref: C3.2, R1.2, U1.1 (K), U2.15 (Vref)
/gain: R16.1, R17.2, S1.5 (COM_3), U3.8 (GAIN)
ADC_CH4: U2.5 (CH4)
D+: J3.2 (D-), U4.14 (GPIO20/U1CTS/ADC2_CH9/CLK_OUT1/USB_D+), U5.3 (CH1)
D-: J3.3 (D+), U4.13 (GPIO19/U1RTS/ADC2_CH8/CLK_OUT2/USB_D-), U5.4 (CH2)
GND: C1.2, C2.1, C3.1, C4.1, C5.2, C6.2, C7.2, C8.1, C9.2, C10.2, C11.2, C12.2, D1.1 (K), D2.1 (K), D3.1 (K), D4.1 (K), H1.1, H2.1, H3.1, H4.1, IC1.12 (GND), J1.1, J1.MH1, J1.MH2, J1.MH3, J2.MP1, J2.MP3, J2.MP4, J2.MP5, J2.P6 (VSS), J3.4 (GND), J4.1, S1.8 (NO_4), SW1.2 (B), SW2.2 (B), U1.2 (A), U2.9 (DGND), U2.14 (AGND), U3.2 (speaker-), U3.4 (VSS), U4.1 (GND), U4.40 (GND), U4.41 (GND), U5.2 (VSS); also elsewhere on the board
unnamed: D1.2 (A), R9.1
unnamed: D2.2 (A), R10.1
unnamed: D3.2 (A), R11.1
unnamed: D4.2 (A), R12.1
unnamed: F1.1, FB1.2
unnamed: IC1.3 (RESET#), R13.1, SW1.1 (A)
unnamed: J1.2, J1.5, U3.1 (speaker+)
unnamed: R15.2, S1.1 (COM_1)
unnamed: R16.2, S1.3 (COM_2)
unnamed: R17.1, S1.7 (COM_4)
SCL: IC1.22 (SCL), U4.5 (GPIO5/TOUCH5/ADC1_CH4)
SDA: IC1.23 (SDA), U4.4 (GPIO4/TOUCH4/ADC1_CH3)
UART0_RX: J4.3
UART0_TX: J4.2
VBUS: FB1.1, J3.1 (VBUS), U5.5 (VCC)

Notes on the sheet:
AUDIO Board + JACK
interupt pin to MCU
USD CARD SOCKET
RC delay recomanded min 10ms wanted 15-20ms
Free safe pins:
Power indicator leds
NOTE: PG 1Meg R so for delay in ms is cap rating in nF ex: 15ms => 15nF
150% rating so 1.5A-2A for me
MCU
ESD protection IC
ESP32-S3 has four strapping pins: • GPIO0 / BOOT • GPIO45 • GPIO46 • GPIO3 GPIO0, GPIO45 and GPIO46 are connected to the chip's internal weak pull-up/pull-down during the chip reset. GPIO3 is floating by default
Internal Pull-up/down 45k Max IC typical current: source 40mA sink 28mA EN pin TTL: 0.75*Vcc+ HIGH 0.25*Vcc- LOW
A1 A0 I2C adredd GND GND 0x40 (0100 000X) GND VCC 0x42 (0100 001X) VCC GND 0x44 (0100 010X) VCC VCC 0x46 (0100 011X)
GPIO EXTENDER
SD CARD
Danger free pins:
USB POWER+DATA
ADC
graphics+ mechanical
1.2mA max at 4.2V 0.3mA min at 3V3
Audio jack
this board has screw terminals at thee audio autpur
BOOOT & RESET

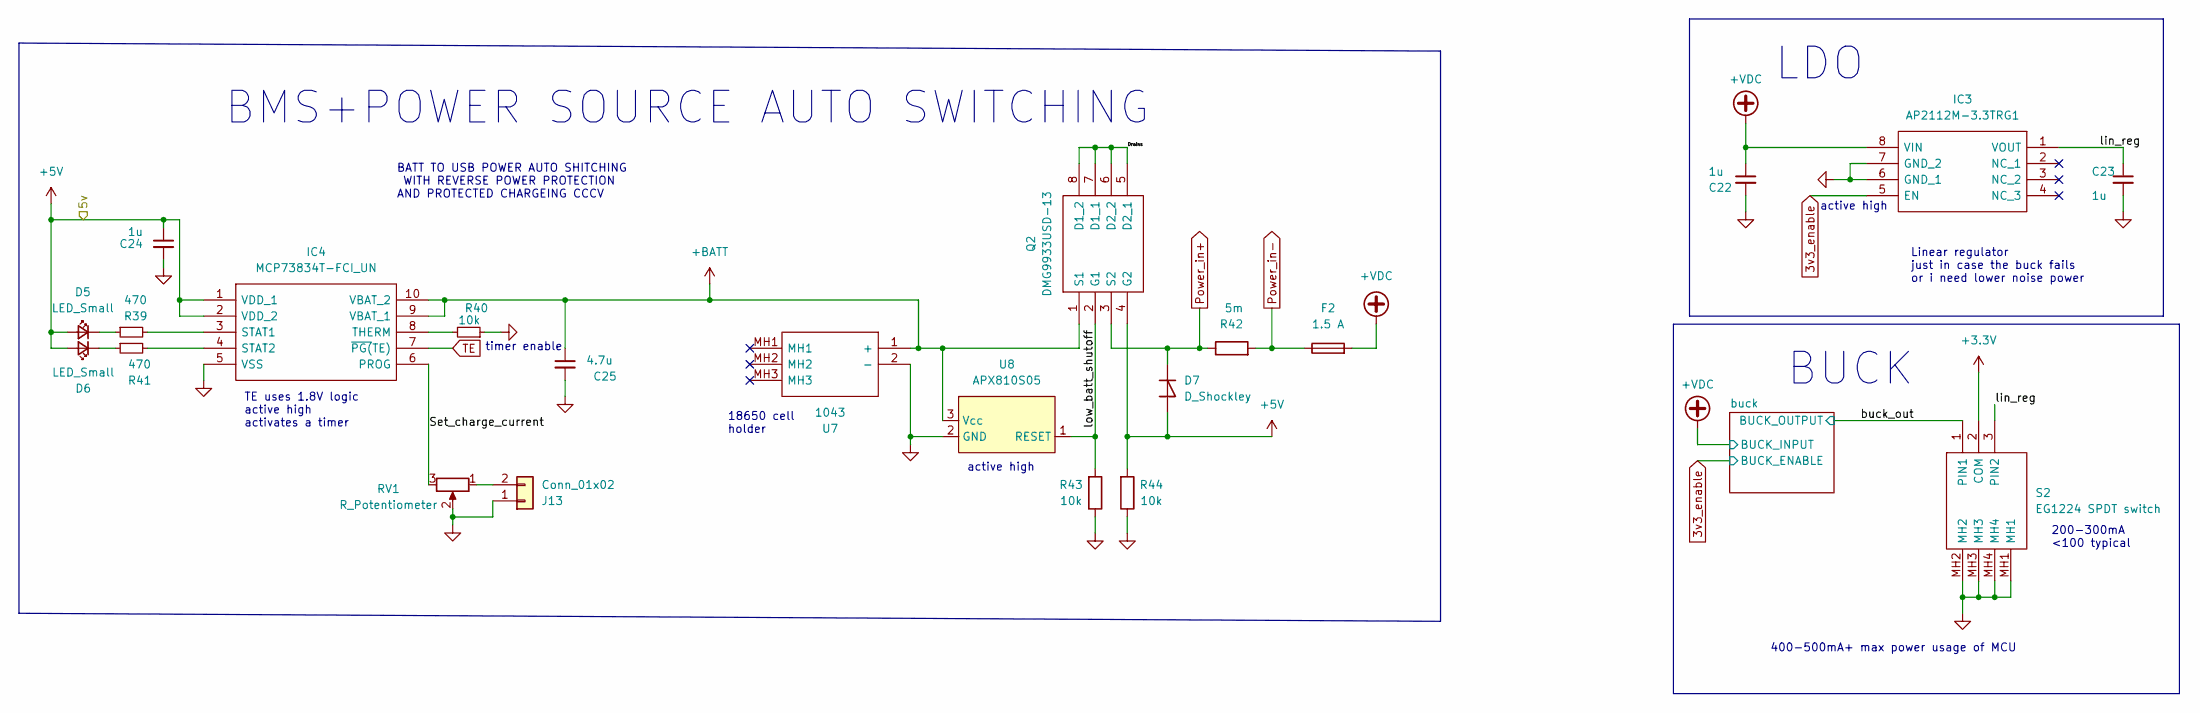
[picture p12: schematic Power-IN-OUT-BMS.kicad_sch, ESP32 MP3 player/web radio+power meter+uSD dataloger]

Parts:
C22, C23: 1u; C_0805_2012Metric_Pad1.18x1.45mm_HandSolder
C24: 1u; C_0603_1608Metric_Pad1.08x0.95mm_HandSolder
C25: 4.7u; C_0603_1608Metric_Pad1.08x0.95mm_HandSolder
D5, D6: LED_Small; LED_0603_1608Metric_Pad1.05x0.95mm_HandSolder
D7: D_Shockley; D_DO-15_P5.08mm_Vertical_AnodeUp
F2: 1.5 A; Fuse_1812_4532Metric
IC3: AP2112M-3.3TRG1; SOIC127P600X170-8N; Mouser Part Number 621-AP2112M-3.3TRG1
IC4: MCP73834T-FCI_UN; SOP50P490X110-10N; Mouser Part Number 579-MCP73834T-FCI/UN
J13: Conn_01x02; PinHeader_1x02_P2.54mm_Vertical
Q2: DMG9933USD-13; SOIC127P600X175-8N; Mouser Part Number 621-DMG9933USD-13
R39, R41: 470; R_0603_1608Metric_Pad0.98x0.95mm_HandSolder
R40, R43, R44: 10k; R_0603_1608Metric_Pad0.98x0.95mm_HandSolder
R42: 5m; R_0612_1632Metric_Pad1.18x3.40mm_HandSolder
RV1: R_Potentiometer; Potentiometer_Bourns_3386F_Vertical
S2: EG1224 SPDT switch; EG1224; Mouser Part Number 612-EG1224
U7: 1043; Mouser Part Number 534-1043
U8: APX810S05; SOT-23

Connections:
3v3_enable: IC3.5 (EN); also elsewhere on the board
+3.3V: S2.2 (COM); also elsewhere on the board
+5V: C24.1, D5.2 (A), D6.2 (A), D7.2 (A), IC4.1 (VDD_1), IC4.2 (VDD_2), Q2.4 (G2), R44.2; also elsewhere on the board
+BATT: C25.1, IC4.9 (VBAT_1), IC4.10 (VBAT_2), Q2.1 (S1), U7.1 (+), U8.3 (Vcc)
+VDC: C22.1, F2.2, IC3.8 (VIN); also elsewhere on the board
/Power-IN-OUT-BMS/Drains: Q2.5 (D2_1), Q2.6 (D2_2), Q2.7 (D1_1), Q2.8 (D1_2)
/Power-IN-OUT-BMS/Set_charge_current: IC4.6 (PROG), RV1.3
/Power-IN-OUT-BMS/buck_out: S2.1 (PIN1); also elsewhere on the board
/Power-IN-OUT-BMS/lin_reg: C23.1, IC3.1 (VOUT), S2.3 (PIN2)
/Power-IN-OUT-BMS/low_batt_shutoff: Q2.2 (G1), R43.2, U8.1 (RESET)
GND: C22.2, C23.2, C24.2, C25.2, IC3.6 (GND_1), IC3.7 (GND_2), IC4.5 (VSS), J13.1, R40.1, R43.1, R44.1, RV1.2, S2.MH1, S2.MH2, S2.MH3, S2.MH4, U7.2 (-), U8.2 (GND); also elsewhere on the board
unnamed: D5.1 (K), R39.1
unnamed: D6.1 (K), R41.1
unnamed: IC4.3 (STAT1), R39.2
unnamed: IC4.4 (STAT2), R41.2
unnamed: IC4.8 (THERM), R40.2
unnamed: J13.2, RV1.1
Power_in+: D7.1 (K), Q2.3 (S2), R42.1; also elsewhere on the board
Power_in-: F2.1, R42.2; also elsewhere on the board
TE: IC4.7 (~PG(TE))

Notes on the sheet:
400-500mA+ max power usage of MCU
active high
timer enable
BUCK
TE uses 1.8V logic active high activates a timer
Linear regulator just in case the buck fails or i need lower noise power
BATT TO USB POWER AUTO SHITCHING WITH REVERSE POWER PROTECTION AND PROTECTED CHARGEING CCCV
18650 cell holder
LDO
200-300mA <100 typical
BMS+POWER SOURCE AUTO SWITCHING

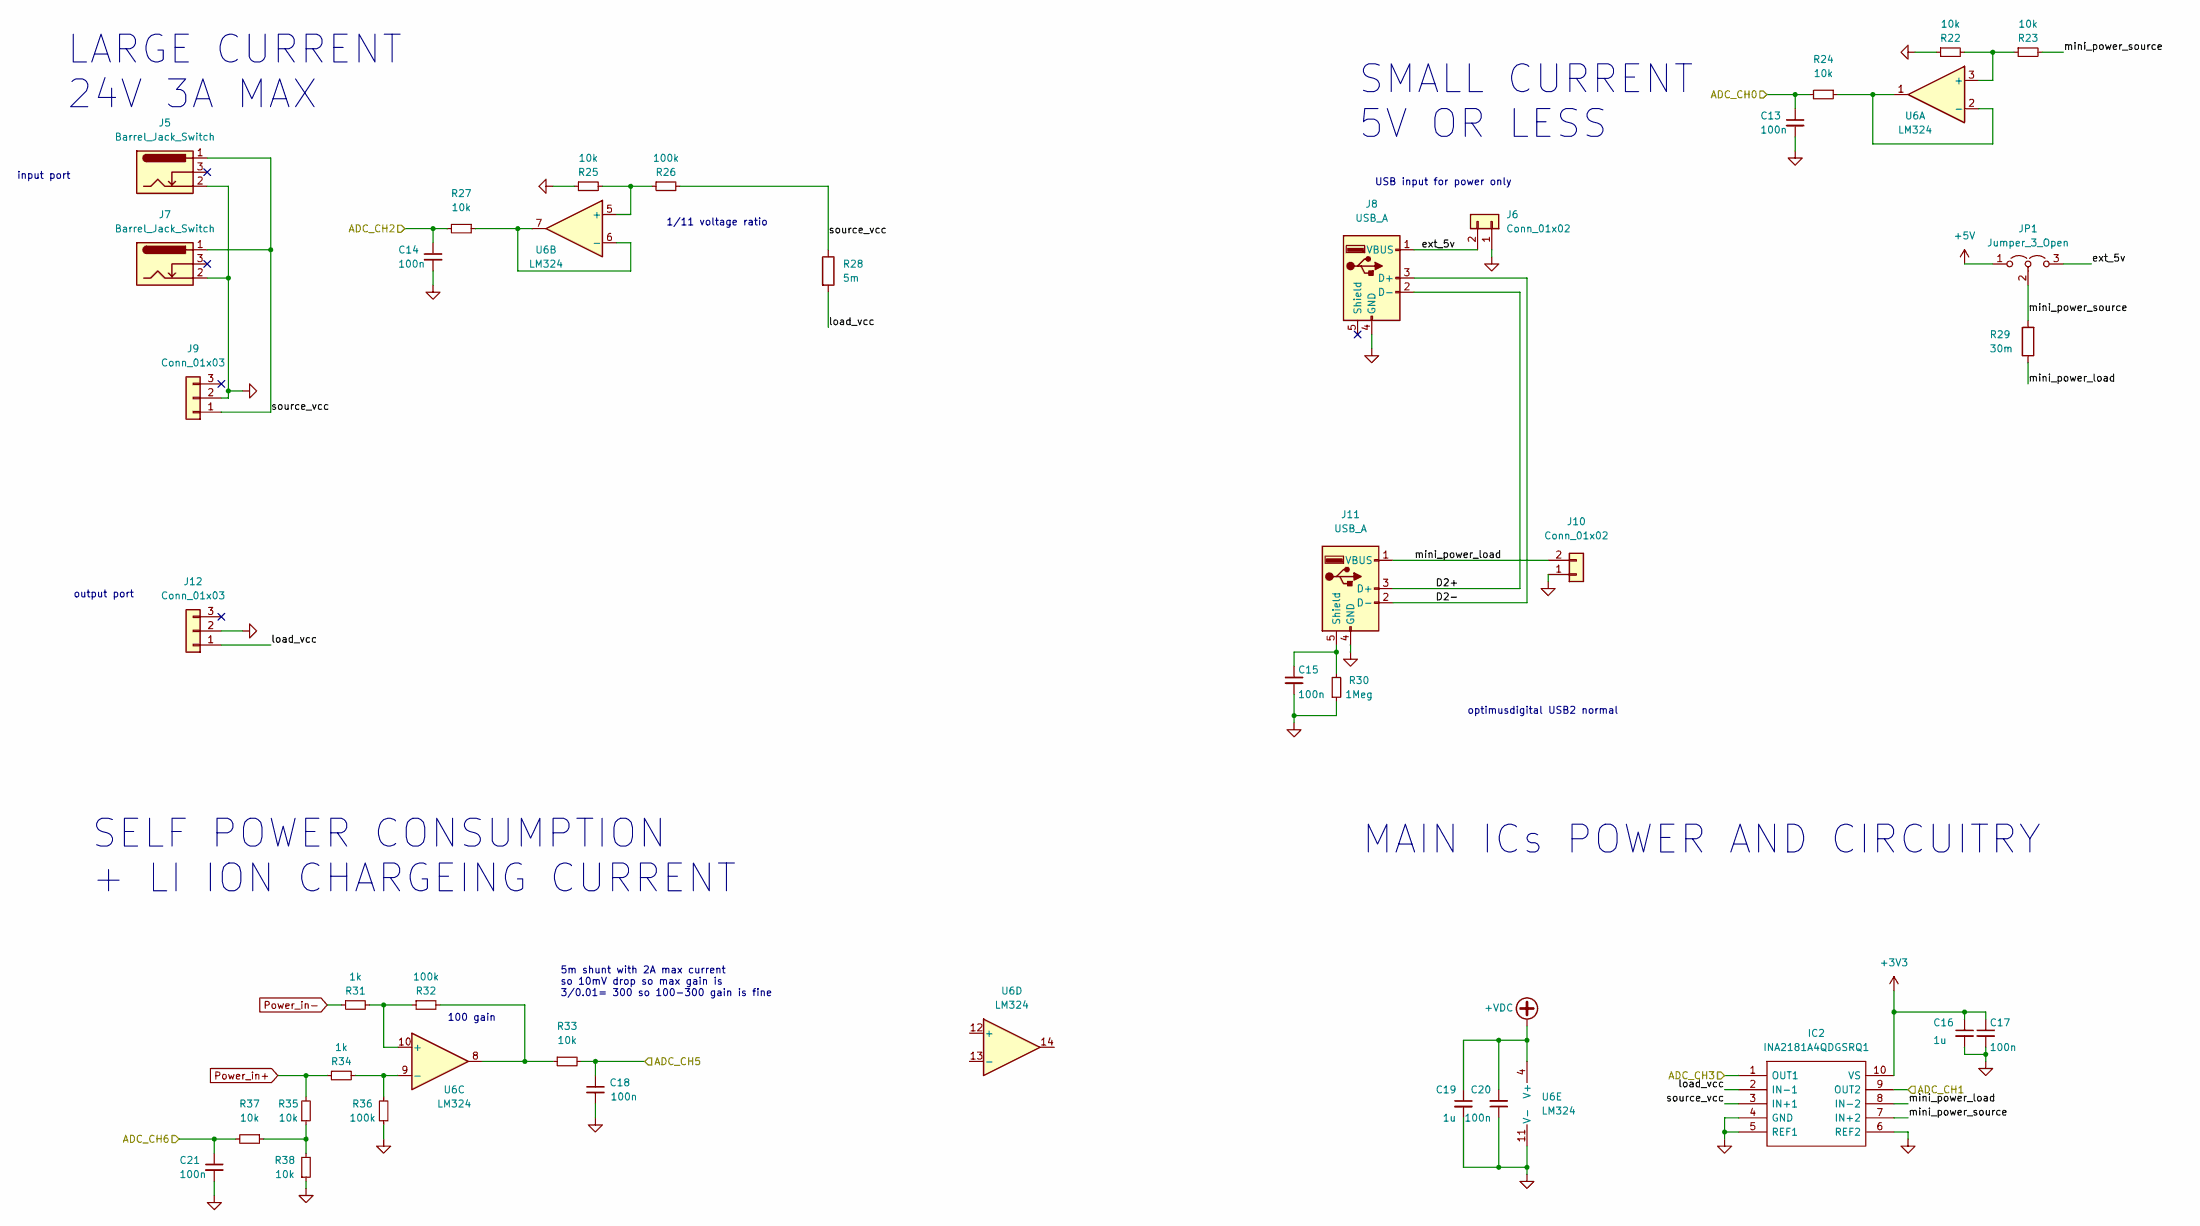
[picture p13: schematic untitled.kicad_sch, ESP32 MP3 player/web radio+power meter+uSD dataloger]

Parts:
C13, C14, C15, C17, C18, C20, C21: 100n; C_0603_1608Metric_Pad1.08x0.95mm_HandSolder
C16, C19: 1u; C_0603_1608Metric_Pad1.08x0.95mm_HandSolder
IC2: INA2181A4QDGSRQ1; SOP50P490X110-10N; Mouser Part Number 595-INA2181A4QDGSRQ1
J5: Barrel_Jack_Switch; DC plug jack 5.5-2.5mm
J6, J10: Conn_01x02; TestPoint_2Pads_Pitch5.08mm_Drill1.3mm
J7: Barrel_Jack_Switch; BarrelJack_Wuerth_6941xx301002
J8, J11: USB_A; USB_A_Molex_67643_Horizontal
J9, J12: Conn_01x03; SCREWTERMINAL-5MM-3
JP1: Jumper_3_Open; PinHeader_1x03_P2.54mm_Vertical
R22, R23, R24, R25, R27, R33, R35, R37, R38: 10k; R_0603_1608Metric_Pad0.98x0.95mm_HandSolder
R26, R32, R36: 100k; R_0603_1608Metric_Pad0.98x0.95mm_HandSolder
R28: 5m; R_0612_1632Metric_Pad1.18x3.40mm_HandSolder
R29: 30m; R_0402_1005Metric_Pad0.72x0.64mm_HandSolder
R30: 1Meg; R_0603_1608Metric_Pad0.98x0.95mm_HandSolder
R31, R34: 1k; R_0603_1608Metric_Pad0.98x0.95mm_HandSolder
U6: LM324

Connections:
+3V3: C16.1, C17.1, IC2.10 (VS); also elsewhere on the board
+5V: JP1.1 (A); also elsewhere on the board
+VDC: C19.1, C20.2, U6.4 (V+); also elsewhere on the board
/POWER_MEASUREMENTS/ADC_CH0: C13.1, R24.2; also elsewhere on the board
/POWER_MEASUREMENTS/ADC_CH1: IC2.9 (OUT2); also elsewhere on the board
/POWER_MEASUREMENTS/ADC_CH2: C14.1, R27.2; also elsewhere on the board
/POWER_MEASUREMENTS/ADC_CH3: IC2.1 (OUT1); also elsewhere on the board
/POWER_MEASUREMENTS/ADC_CH5: C18.1, R33.2; also elsewhere on the board
/POWER_MEASUREMENTS/ADC_CH6: C21.1, R37.2; also elsewhere on the board
/POWER_MEASUREMENTS/D2+: J8.2 (D-), J11.3 (D+)
/POWER_MEASUREMENTS/D2-: J8.3 (D+), J11.2 (D-)
/POWER_MEASUREMENTS/ext_5v: J6.2, J8.1 (VBUS), JP1.3 (B)
/POWER_MEASUREMENTS/load_vcc: IC2.2 (IN-1), J12.1, R28.2
/POWER_MEASUREMENTS/mini_power_load: IC2.8 (IN-2), J10.2, J11.1 (VBUS), R29.1
/POWER_MEASUREMENTS/mini_power_source: IC2.7 (IN+2), JP1.2 (C), R23.2, R29.2
/POWER_MEASUREMENTS/source_vcc: IC2.3 (IN+1), J5.1, J7.1, J9.1, R26.2, R28.1
GND: C13.2, C14.2, C15.2, C16.2, C17.2, C18.2, C19.2, C20.1, C21.2, IC2.4 (GND), IC2.5 (REF1), IC2.6 (REF2), J5.2, J6.1, J7.2, J8.4 (GND), J9.2, J10.1, J11.4 (GND), J12.2, R22.1, R25.1, R30.1, R36.1, R38.1, U6.11 (V-); also elsewhere on the board
unnamed: C15.1, J11.5 (Shield), R30.2
unnamed: R22.2, R23.1, U6.3 (+)
unnamed: R24.1, U6.1, U6.2 (-)
unnamed: R25.2, R26.1, U6.5 (+)
unnamed: R27.1, U6.6 (-), U6.7
unnamed: R31.2, R32.1, U6.10 (+)
unnamed: R32.2, R33.1, U6.8
unnamed: R34.2, R36.2, U6.9 (-)
unnamed: R35.1, R37.1, R38.2
Power_in+: R34.1, R35.2; also elsewhere on the board
Power_in-: R31.1; also elsewhere on the board

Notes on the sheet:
USB input for power only
100 gain
SMALL CURRENT 5V OR LESS
1/11 voltage ratio
input port
5m shunt with 2A max current so 10mV drop so max gain is 3/0.01= 300 so 100-300 gain is fine
SELF POWER CONSUMPTION + LI ION CHARGEING CURRENT
output port
LARGE CURRENT 24V 3A MAX
MAIN ICs POWER AND CIRCUITRY
optimusdigital USB2 normal

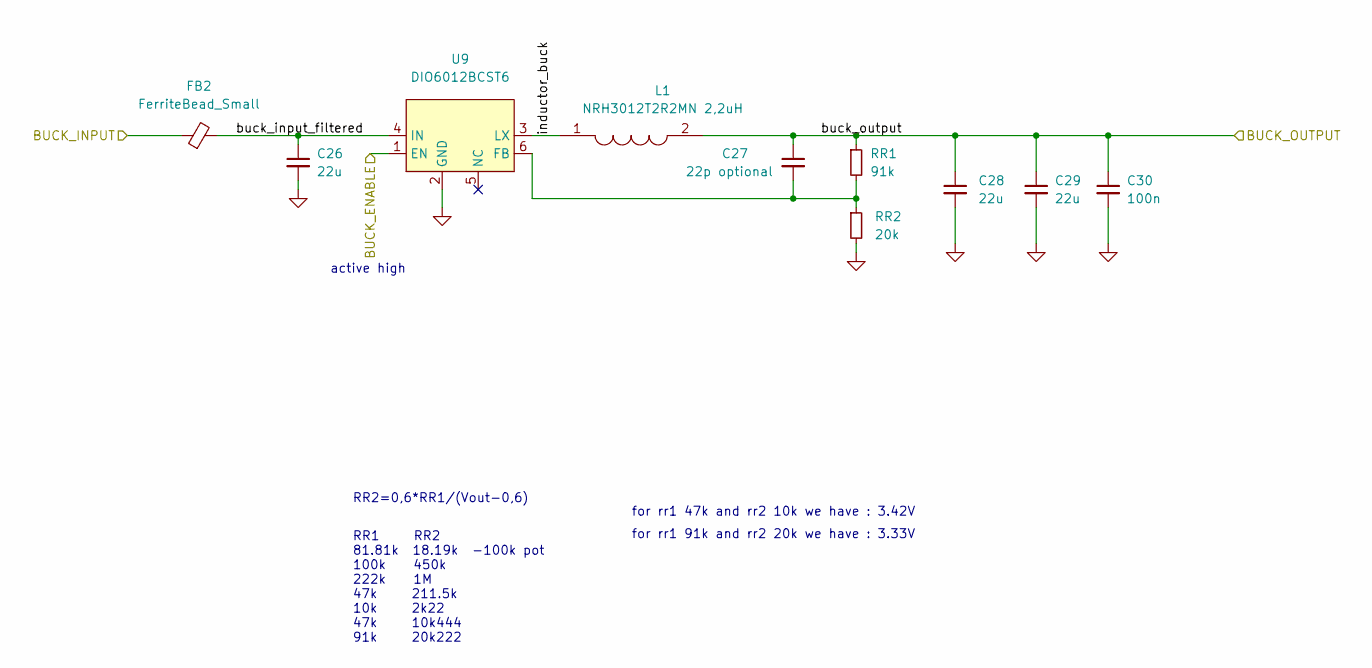
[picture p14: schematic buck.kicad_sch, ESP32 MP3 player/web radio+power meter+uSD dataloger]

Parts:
C26, C28, C29: 22u; C_0805_2012Metric
C27: 22p optional; C_0603_1608Metric_Pad1.08x0.95mm_HandSolder
C30: 100n; C_0603_1608Metric
FB2: FerriteBead_Small; R_0603_1608Metric_Pad0.98x0.95mm_HandSolder
L1: NRH3012T2R2MN 2,2uH; NRH3012T220MNV; Mouser Part Number 963-NRH3012T2R2MN
RR1: 91k; R_0805_2012Metric_Pad1.20x1.40mm_HandSolder
RR2: 20k; R_0805_2012Metric_Pad1.20x1.40mm_HandSolder
U9: DIO6012BCST6; SOT-23-6_Handsoldering

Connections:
3v3_enable: U9.1 (EN); also elsewhere on the board
+VDC: FB2.1; also elsewhere on the board
/Power-IN-OUT-BMS/buck/buck_input_filtered: C26.1, FB2.2, U9.4 (IN)
/Power-IN-OUT-BMS/buck/inductor_buck: L1.1, U9.3 (LX)
/Power-IN-OUT-BMS/buck_out: C27.1, C28.1, C29.1, C30.1, L1.2, RR1.1; also elsewhere on the board
GND: C26.2, C28.2, C29.2, C30.2, RR2.2, U9.2 (GND); also elsewhere on the board
unnamed: C27.2, RR1.2, RR2.1, U9.6 (FB)

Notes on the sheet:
for rr1 47k and rr2 10k we have : 3.42V
for rr1 91k and rr2 20k we have : 3.33V
RR2=0,6*RR1/(Vout-0,6)
active high
RR1 RR2 81.81k 18.19k -100k pot 100k 450k 222k 1M 47k 211.5k 10k 2k22 47k 10k444 91k 20k222

Board: 2 copper layers, 128 parts (7 on the bottom side), 81 nets, no tracks yet.

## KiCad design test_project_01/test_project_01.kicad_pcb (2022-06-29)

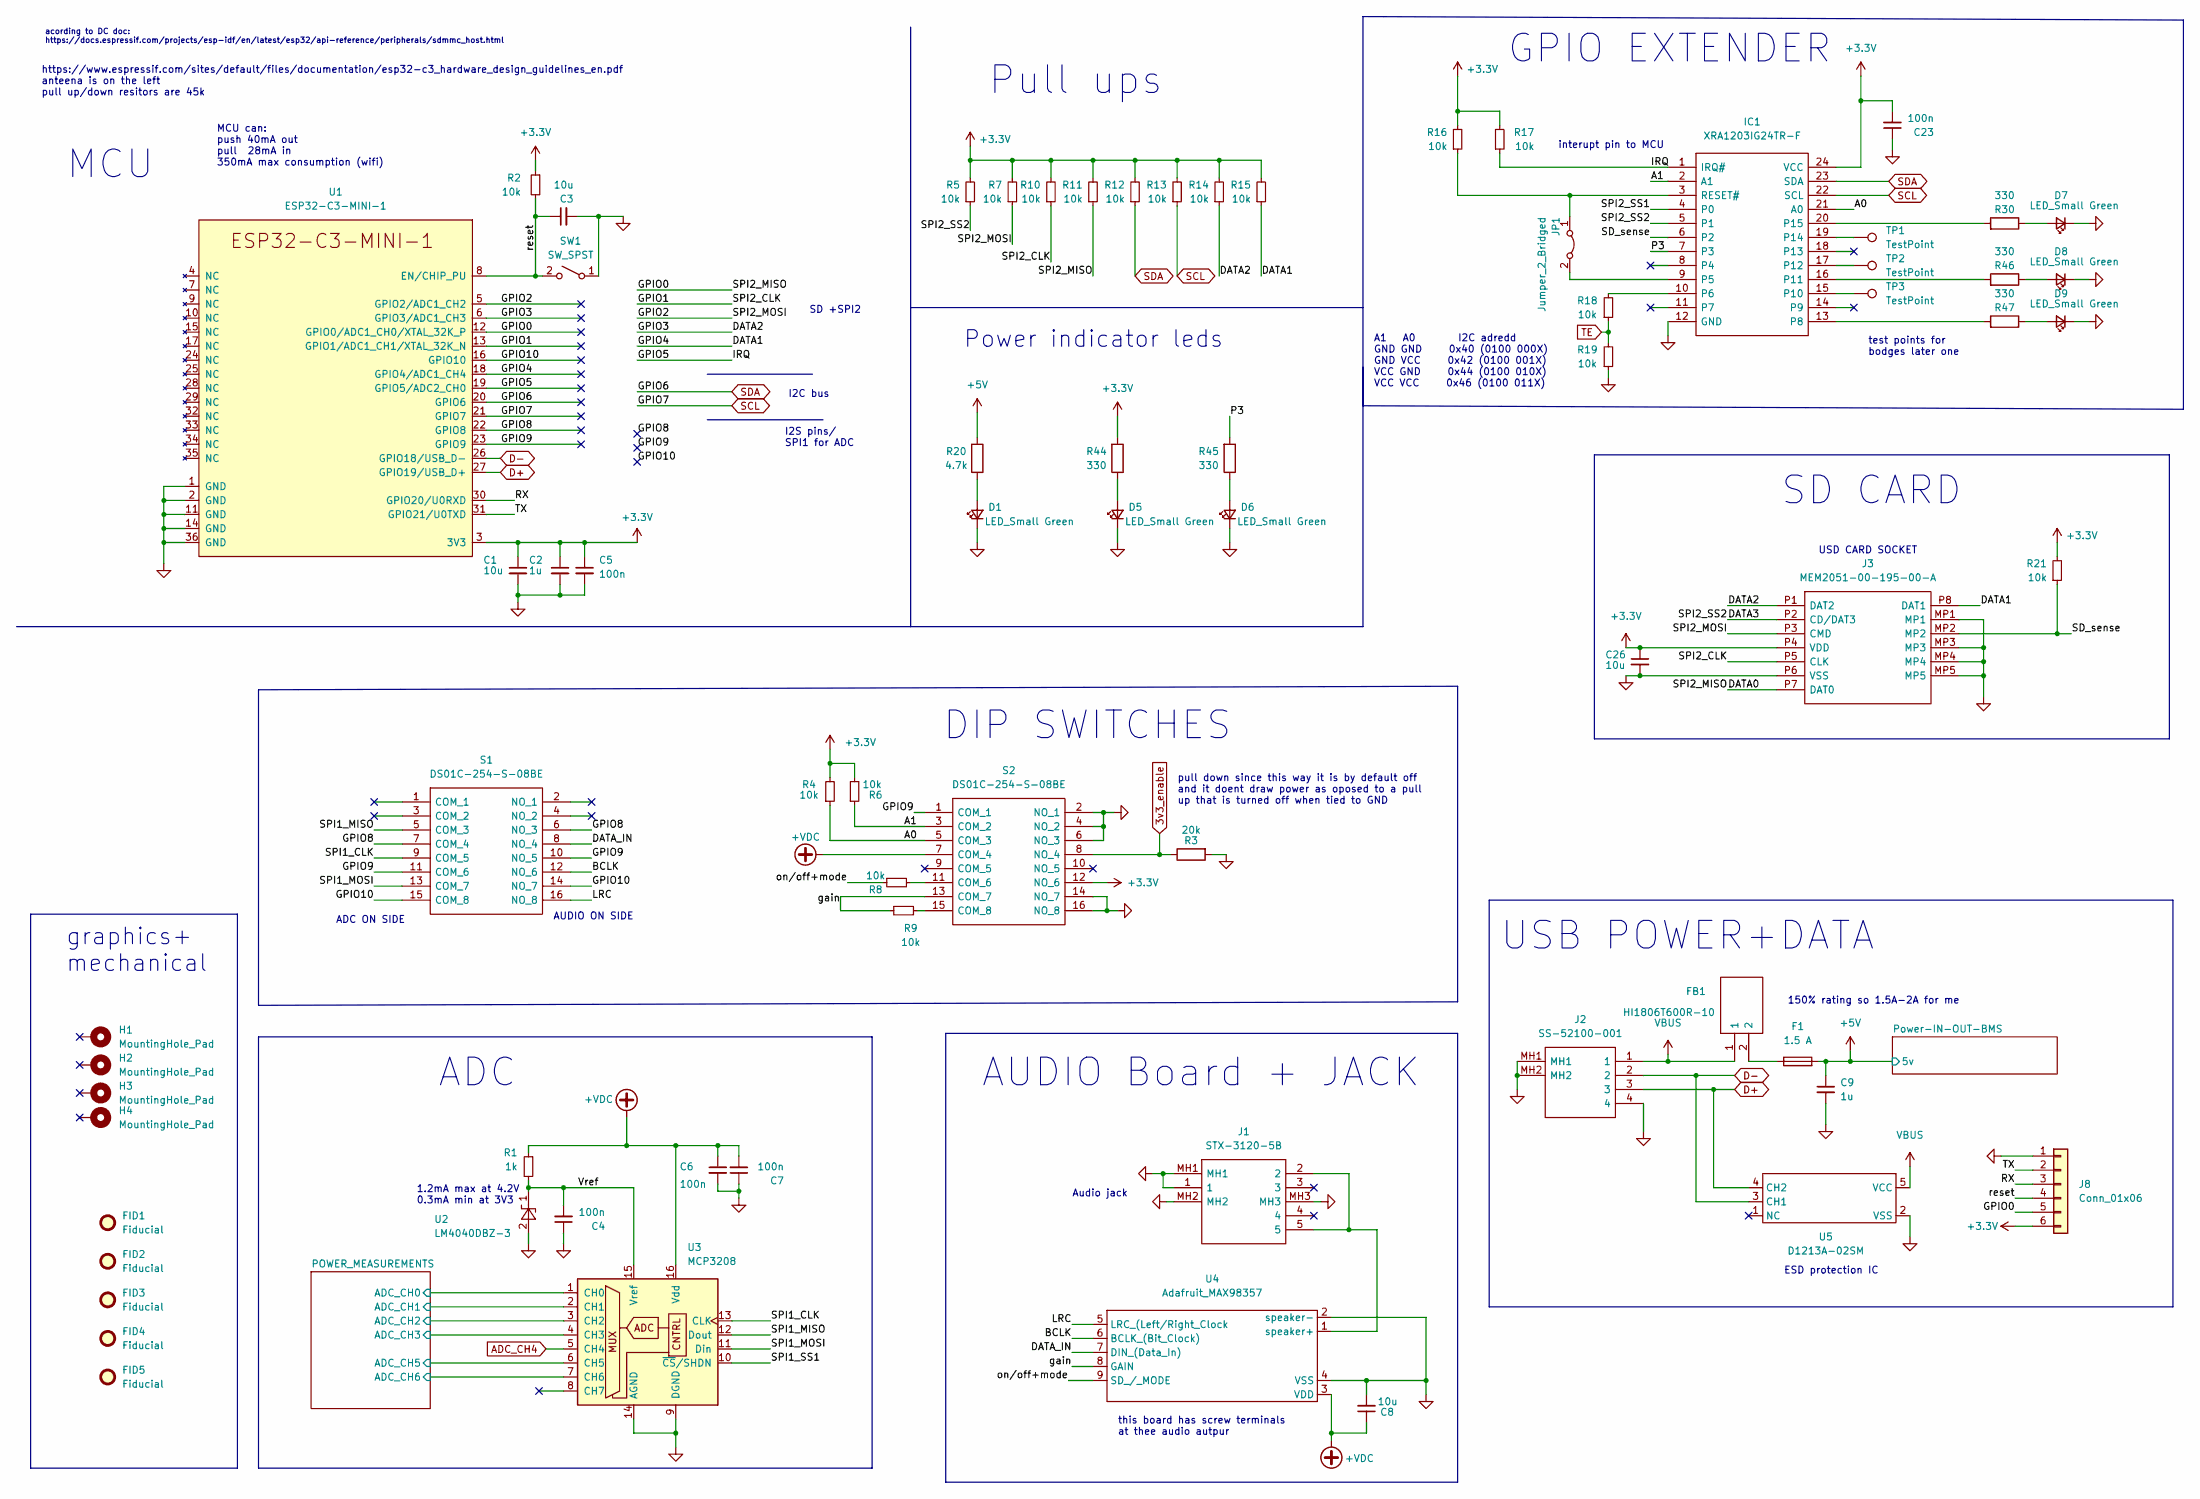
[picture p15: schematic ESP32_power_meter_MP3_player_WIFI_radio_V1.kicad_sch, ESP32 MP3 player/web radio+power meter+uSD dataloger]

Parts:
C1, C3, C8, C26: 10u; C_0603_1608Metric_Pad1.08x0.95mm_HandSolder
C2, C9: 1u; C_0603_1608Metric_Pad1.08x0.95mm_HandSolder
C4, C5, C6, C7, C23: 100n; C_0603_1608Metric_Pad1.08x0.95mm_HandSolder
D1, D5, D6, D7, D8, D9: LED_Small Green; LED_0603_1608Metric_Pad1.05x0.95mm_HandSolder
F1: 1.5 A; Fuse_0603_1608Metric_Pad1.05x0.95mm_HandSolder
FB1: HI1806T600R-10; BEADC4516X185N; Mouser Part Number 875-HI1806T600R-10
FID1: Fiducial; Fiducial_0.5mm_Mask1mm
FID2: Fiducial; Polarity_Center_Positive_6mm_SilkScreen
FID3: Fiducial; OSHW-Logo_5.7x6mm_SilkScreen
FID4: Fiducial; KiCad-Logo2_6mm_SilkScreen
FID5: Fiducial; WEEE-Logo_5.6x8mm_SilkScreen
H1, H2, H3, H4: MountingHole_Pad; MountingHole_3.2mm_M3
IC1: XRA1203IG24TR-F; SOP65P640X120-24N; Mouser Part Number 701-XRA1203IG24TR-F
J1: STX-3120-5B; STX31205B; Mouser Part Number 806-STX-3120-5B
J2: SS-52100-001; SS52100001; Mouser Part Number 530-SS-52100-001
J3: MEM2051-00-195-00-A; MEM20510019500A; Mouser Part Number 640-MEM20510019500A
J8: Conn_01x06; PinHeader_1x06_P2.54mm_Vertical
JP1: Jumper_2_Bridged; SolderJumper-2_P1.3mm_Bridged_RoundedPad1.0x1.5mm
R1: 1k; R_0603_1608Metric_Pad0.98x0.95mm_HandSolder
R2, R4, R5, R6, R7, R8, R9, R10, R11, R12, R13, R14, R15, R16, R17, R18, R19, R21: 10k; R_0603_1608Metric_Pad0.98x0.95mm_HandSolder
R3: 20k; R_0603_1608Metric_Pad0.98x0.95mm_HandSolder
R20: 4.7k; R_0805_2012Metric
R30, R44, R45, R46, R47: 330; R_0603_1608Metric_Pad0.98x0.95mm_HandSolder
S1, S2: DS01C-254-S-08BE; DS01C254S08BE; Mouser Part Number 490-DS01C-254-S-08BE
SW1: SW_SPST; PTS526SM15SMTR2LFS
TP1, TP2, TP3: TestPoint; TestPoint_Pad_1.0x1.0mm
U1: ESP32-C3-MINI-1; ESP32-C3-MINI-1_Hand-Soldering
U2: LM4040DBZ-3; SOT-23
U3: MCP3208; SOIC-16_3.9x9.9mm_P1.27mm
U4: Adafruit_MAX98357; Adafruit MAX98357 I2S Class-D Mono
U5: D1213A-02SM; SOT-23-5

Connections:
3v3_enable: R3.1, S2.8 (NO_4); also elsewhere on the board
+5V: C9.1, F1.2, R20.2; also elsewhere on the board
+VDC: C6.1, C7.2, C8.1, R1.1, S2.7 (COM_4), U3.16 (Vdd), U4.3 (VDD); also elsewhere on the board
/A0: IC1.21 (A0), R4.1, S2.5 (COM_3)
/A1: IC1.2 (A1), R6.1, S2.3 (COM_2)
/BCLK: S1.12 (NO_6), U4.6 (BCLK_(Bit_Clock))
/DATA0: J3.P7 (DAT0), J8.5, R11.1, U1.12 (GPIO0/ADC1_CH0/XTAL_32K_P)
/DATA1: J3.P8 (DAT1), R15.1, U1.18 (GPIO4/ADC1_CH4)
/DATA2: J3.P1 (DAT2), R14.1, U1.6 (GPIO3/ADC1_CH3)
/DATA3: IC1.5 (P1), J3.P2 (CD/DAT3), R5.1
/DATA_IN: S1.8 (NO_4), U4.7 (DIN_(Data_In))
/GPIO1: J3.P5 (CLK), R10.1, U1.13 (GPIO1/ADC1_CH1/XTAL_32K_N)
/GPIO2: J3.P3 (CMD), R7.1, U1.5 (GPIO2/ADC1_CH2)
/GPIO5: IC1.1 (IRQ#), R17.1, U1.19 (GPIO5/ADC2_CH0)
/GPIO8: S1.6 (NO_3), S1.7 (COM_4), U1.22 (GPIO8)
/GPIO9: S1.10 (NO_5), S1.11 (COM_6), S2.1 (COM_1), U1.23 (GPIO9)
/GPIO10: S1.14 (NO_7), S1.15 (COM_8), U1.16 (GPIO10)
/LRC: S1.16 (NO_8), U4.5 (LRC_(Left/Right_Clock)
/P3: IC1.7 (P3), R45.2
/RX: J8.3, U1.30 (GPIO20/U0RXD)
/SD_sense: IC1.6 (P2), J3.MP2, R21.1
/SPI1_CLK: S1.9 (COM_5), U3.13 (CLK)
/SPI1_MISO: S1.5 (COM_3), U3.12 (Dout)
/SPI1_MOSI: S1.13 (COM_7), U3.11 (Din)
/SPI1_SS1: U3.10 (~CS/SHDN)
/SPI2_SS1: IC1.4 (P0)
/TX: J8.2, U1.31 (GPIO21/U0TXD)
/Vref: C4.2, R1.2, U2.1 (K), U3.15 (Vref)
/gain: R9.1, S2.13 (COM_7), U4.8 (GAIN)
/on/off+mode: R8.1, U4.9 (SD_/_MODE)
/reset: C3.1, J8.4, R2.2, SW1.2 (B), U1.8 (EN/CHIP_PU)
ADC_CH0: U3.1 (CH0); also elsewhere on the board
ADC_CH1: U3.2 (CH1); also elsewhere on the board
ADC_CH2: U3.3 (CH2); also elsewhere on the board
ADC_CH3: U3.4 (CH3); also elsewhere on the board
ADC_CH4: U3.5 (CH4); also elsewhere on the board
ADC_CH5: U3.6 (CH5); also elsewhere on the board
ADC_CH6: U3.7 (CH6); also elsewhere on the board
D+: J2.3, U1.27 (GPIO19/USB_D+), U5.4 (CH2)
D-: J2.2, U1.26 (GPIO18/USB_D-), U5.3 (CH1)
GND: C1.2, C2.2, C3.2, C4.1, C5.2, C6.2, C7.1, C8.2, C9.2, C23.1, C26.2, D1.1 (K), D5.1 (K), D6.1 (K), D7.1 (K), D8.1 (K), D9.1 (K), IC1.12 (GND), J1.1, J1.MH1, J1.MH2, J1.MH3, J2.4, J2.MH1, J2.MH2, J3.MP1, J3.MP3, J3.MP4, J3.MP5, J3.P6 (VSS), J8.1, R3.2, R19.1, S2.2 (NO_1), S2.4 (NO_2), S2.6 (NO_3), S2.14 (NO_7), S2.16 (NO_8), SW1.1 (A), U1.1 (GND), U1.2 (GND), U1.11 (GND), U1.14 (GND), U1.36 (GND), U2.2 (A), U3.9 (DGND), U3.14 (AGND), U4.2 (speaker-), U4.4 (VSS), U5.2 (VSS); also elsewhere on the board
unnamed: D1.2 (A), R20.1
unnamed: D5.2 (A), R44.1
unnamed: D6.2 (A), R45.1
unnamed: D7.2 (A), R30.1
unnamed: D8.2 (A), R46.1
unnamed: D9.2 (A), R47.1
unnamed: F1.1, FB1.2
unnamed: IC1.3 (RESET#), JP1.1 (A), R16.1
unnamed: IC1.9 (P5), JP1.2 (B)
unnamed: IC1.10 (P6), R18.2
unnamed: J1.2, J1.5, U4.1 (speaker+)
unnamed: R8.2, S2.11 (COM_6)
unnamed: R9.2, S2.15 (COM_8)
unnamed: IC1.20 (P15), R30.2
unnamed: IC1.16 (P11), R46.2
unnamed: IC1.13 (P8), R47.2
unnamed: IC1.19 (P14), TP1.1
unnamed: IC1.17 (P12), TP2.1
unnamed: IC1.15 (P10), TP3.1
SCL: IC1.22 (SCL), R13.1, U1.21 (GPIO7)
SDA: IC1.23 (SDA), R12.1, U1.20 (GPIO6)
TE: R18.1, R19.2; also elsewhere on the board
VBUS: FB1.1, J2.1, U5.5 (VCC)

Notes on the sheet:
Pull ups
AUDIO Board + JACK
interupt pin to MCU
USD CARD SOCKET
AUDIO ON SIDE
MCU can: push 40mA out pull 28mA in 350mA max consumption (wifi)
test points for bodges later one
https://www.espressif.com/sites/default/files/documentation/esp32-c3_hardware_design_guidelines_en.pdf anteena is on the left pull up/down resitors are 45k
DIP SWITCHES
I2S pins/ SPI1 for ADC
pull down since this way it is by default off and it doent draw power as oposed to a pull up that is turned off when tied to GND
Power indicator leds
150% rating so 1.5A-2A for me
ESD protection IC
ADC ON SIDE
A1 A0 I2C adredd GND GND 0x40 (0100 000X) GND VCC 0x42 (0100 001X) VCC GND 0x44 (0100 010X) VCC VCC 0x46 (0100 011X)
GPIO EXTENDER
SD CARD
USB POWER+DATA
ADC
SD +SPI2
I2C bus
graphics+ mechanical
acording to DC doc: https://docs.espressif.com/projects/esp-idf/en/latest/esp32/api-reference/peripherals/sdmmc_host.html
1.2mA max at 4.2V 0.3mA min at 3V3
Audio jack
this board has screw terminals at thee audio autpur
MCU

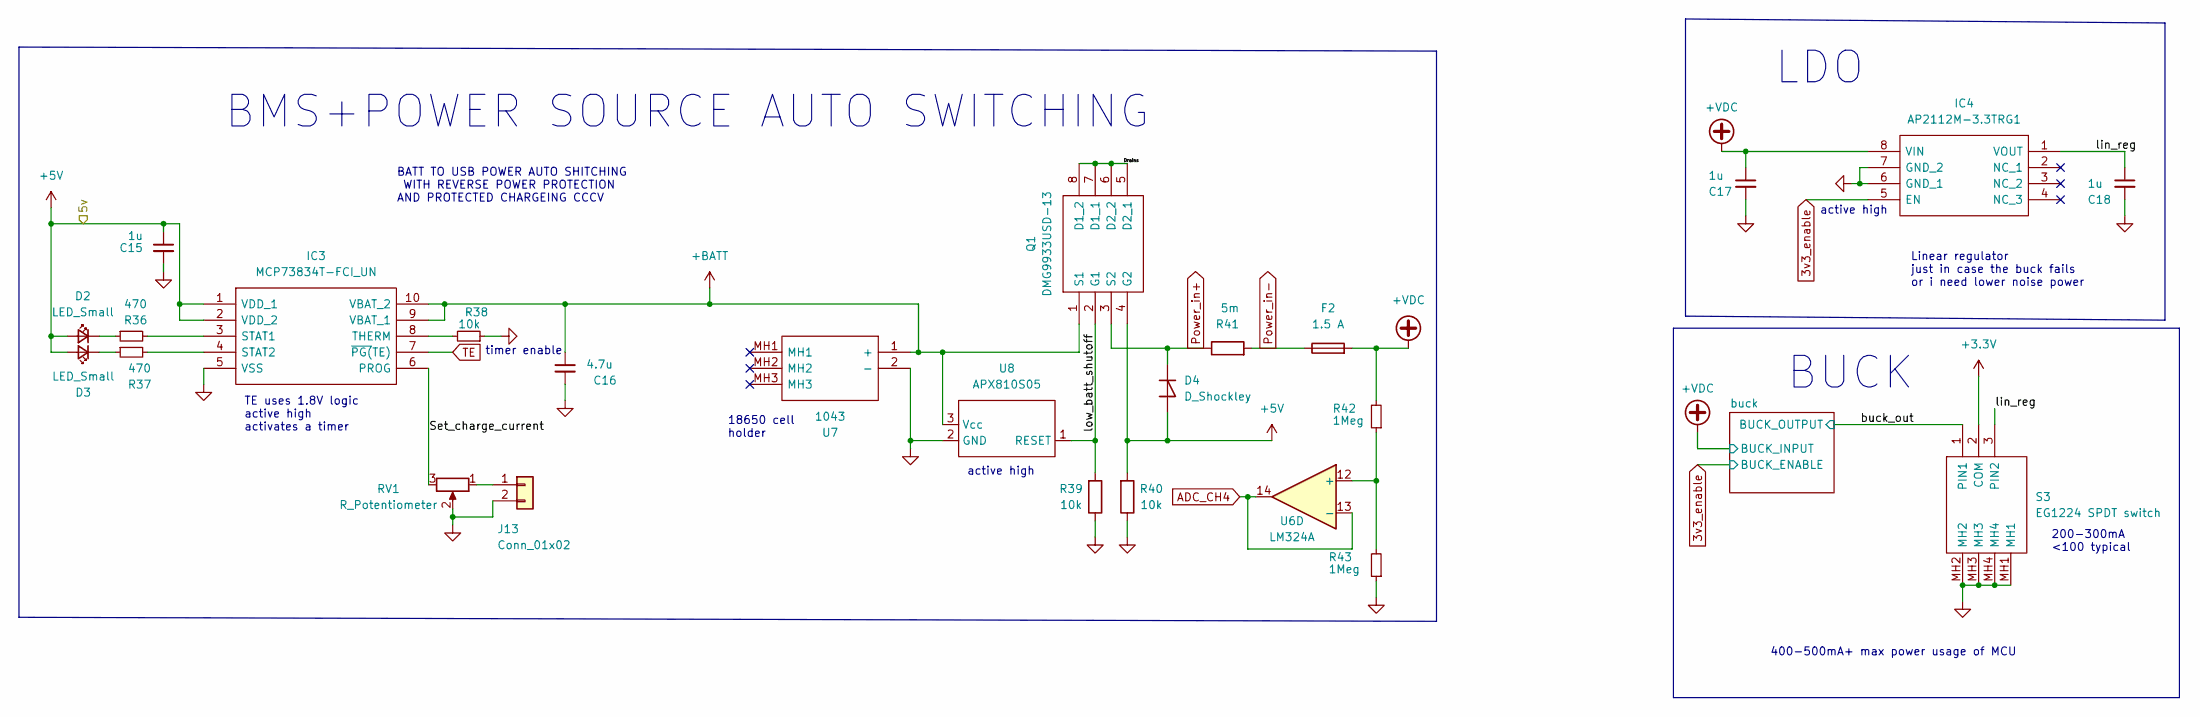
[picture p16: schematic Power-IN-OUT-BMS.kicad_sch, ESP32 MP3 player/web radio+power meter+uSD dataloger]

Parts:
C15: 1u; C_0603_1608Metric_Pad1.08x0.95mm_HandSolder
C16: 4.7u; C_0603_1608Metric_Pad1.08x0.95mm_HandSolder
C17, C18: 1u; C_0805_2012Metric_Pad1.18x1.45mm_HandSolder
D2, D3: LED_Small; LED_0603_1608Metric_Pad1.05x0.95mm_HandSolder
D4: D_Shockley; D_DO-15_P5.08mm_Vertical_AnodeUp
F2: 1.5 A; Fuse_0603_1608Metric_Pad1.05x0.95mm_HandSolder
IC3: MCP73834T-FCI_UN; SOP50P490X110-10N; Mouser Part Number 579-MCP73834T-FCI/UN
IC4: AP2112M-3.3TRG1; SOIC127P600X170-8N; Mouser Part Number 621-AP2112M-3.3TRG1
J13: Conn_01x02; PinHeader_1x02_P2.54mm_Vertical
Q1: DMG9933USD-13; SOIC127P600X175-8N; Mouser Part Number 621-DMG9933USD-13
R36, R37: 470; R_0603_1608Metric_Pad0.98x0.95mm_HandSolder
R38, R39, R40: 10k; R_0603_1608Metric_Pad0.98x0.95mm_HandSolder
R41: 5m; R_0612_1632Metric_Pad1.18x3.40mm_HandSolder
R42, R43: 1Meg; R_0603_1608Metric_Pad0.98x0.95mm_HandSolder
RV1: R_Potentiometer; Potentiometer_Bourns_3386F_Vertical
S3: EG1224 SPDT switch; EG1224; Mouser Part Number 612-EG1224
U6: LM324A; SOIC-14_3.9x8.7mm_P1.27mm
U7: 1043; Mouser Part Number 534-1043
U8: APX810S05; SOT-23

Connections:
3v3_enable: IC4.5 (EN); also elsewhere on the board
+5V: C15.1, D2.2 (A), D3.2 (A), D4.2 (A), IC3.1 (VDD_1), IC3.2 (VDD_2), Q1.4 (G2), R40.2; also elsewhere on the board
+BATT: C16.1, IC3.9 (VBAT_1), IC3.10 (VBAT_2), Q1.1 (S1), U7.1 (+), U8.3 (Vcc)
+VDC: C17.1, F2.2, IC4.8 (VIN), R42.2; also elsewhere on the board
/Power-IN-OUT-BMS/Drains: Q1.5 (D2_1), Q1.6 (D2_2), Q1.7 (D1_1), Q1.8 (D1_2)
/Power-IN-OUT-BMS/Set_charge_current: IC3.6 (PROG), RV1.3
/Power-IN-OUT-BMS/buck_out: S3.1 (PIN1); also elsewhere on the board
/Power-IN-OUT-BMS/lin_reg: C18.1, IC4.1 (VOUT), S3.3 (PIN2)
/Power-IN-OUT-BMS/low_batt_shutoff: Q1.2 (G1), R39.2, U8.1 (RESET)
ADC_CH4: U6.13 (-), U6.14; also elsewhere on the board
GND: C15.2, C16.2, C17.2, C18.2, IC3.5 (VSS), IC4.6 (GND_1), IC4.7 (GND_2), J13.2, R38.1, R39.1, R40.1, R43.1, RV1.2, S3.MH1, S3.MH2, S3.MH3, S3.MH4, U7.2 (-), U8.2 (GND); also elsewhere on the board
unnamed: D2.1 (K), R36.1
unnamed: D3.1 (K), R37.1
unnamed: IC3.3 (STAT1), R36.2
unnamed: IC3.4 (STAT2), R37.2
unnamed: IC3.8 (THERM), R38.2
unnamed: J13.1, RV1.1
unnamed: R42.1, R43.2, U6.12 (+)
Power_in+: D4.1 (K), Q1.3 (S2), R41.1; also elsewhere on the board
Power_in-: F2.1, R41.2; also elsewhere on the board
TE: IC3.7 (~PG(TE)); also elsewhere on the board

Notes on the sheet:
400-500mA+ max power usage of MCU
active high
timer enable
BUCK
TE uses 1.8V logic active high activates a timer
Linear regulator just in case the buck fails or i need lower noise power
BATT TO USB POWER AUTO SHITCHING WITH REVERSE POWER PROTECTION AND PROTECTED CHARGEING CCCV
18650 cell holder
LDO
200-300mA <100 typical
BMS+POWER SOURCE AUTO SWITCHING

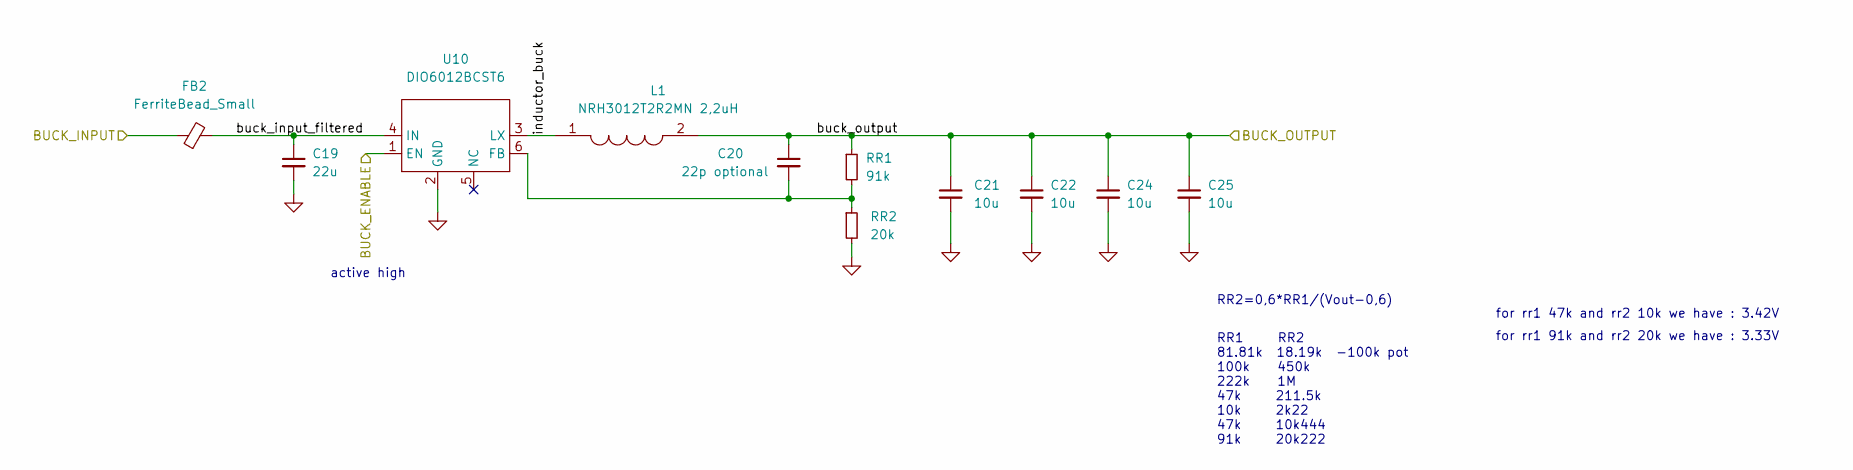
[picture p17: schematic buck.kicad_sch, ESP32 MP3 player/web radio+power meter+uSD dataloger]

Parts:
C19: 22u; CP_Radial_D5.0mm_P2.00mm
C20: 22p optional; C_0603_1608Metric_Pad1.08x0.95mm_HandSolder
C21, C22, C24, C25: 10u; C_0805_2012Metric
FB2: FerriteBead_Small; R_0402_1005Metric_Pad0.72x0.64mm_HandSolder
L1: NRH3012T2R2MN 2,2uH; NRH3012T220MNV; Mouser Part Number 963-NRH3012T2R2MN
RR1: 91k; R_0805_2012Metric_Pad1.20x1.40mm_HandSolder
RR2: 20k; R_0805_2012Metric_Pad1.20x1.40mm_HandSolder
U10: DIO6012BCST6; SOT-23-6_Handsoldering

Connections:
3v3_enable: U10.1 (EN); also elsewhere on the board
+VDC: FB2.1; also elsewhere on the board
/Power-IN-OUT-BMS/buck/buck_input_filtered: C19.1, FB2.2, U10.4 (IN)
/Power-IN-OUT-BMS/buck/inductor_buck: L1.1, U10.3 (LX)
/Power-IN-OUT-BMS/buck_out: C20.1, C21.1, C22.1, C24.1, C25.1, L1.2, RR1.1; also elsewhere on the board
GND: C19.2, C21.2, C22.2, C24.2, C25.2, RR2.2, U10.2 (GND); also elsewhere on the board
unnamed: C20.2, RR1.2, RR2.1, U10.6 (FB)

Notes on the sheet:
for rr1 47k and rr2 10k we have : 3.42V
for rr1 91k and rr2 20k we have : 3.33V
RR2=0,6*RR1/(Vout-0,6)
active high
RR1 RR2 81.81k 18.19k -100k pot 100k 450k 222k 1M 47k 211.5k 10k 2k22 47k 10k444 91k 20k222

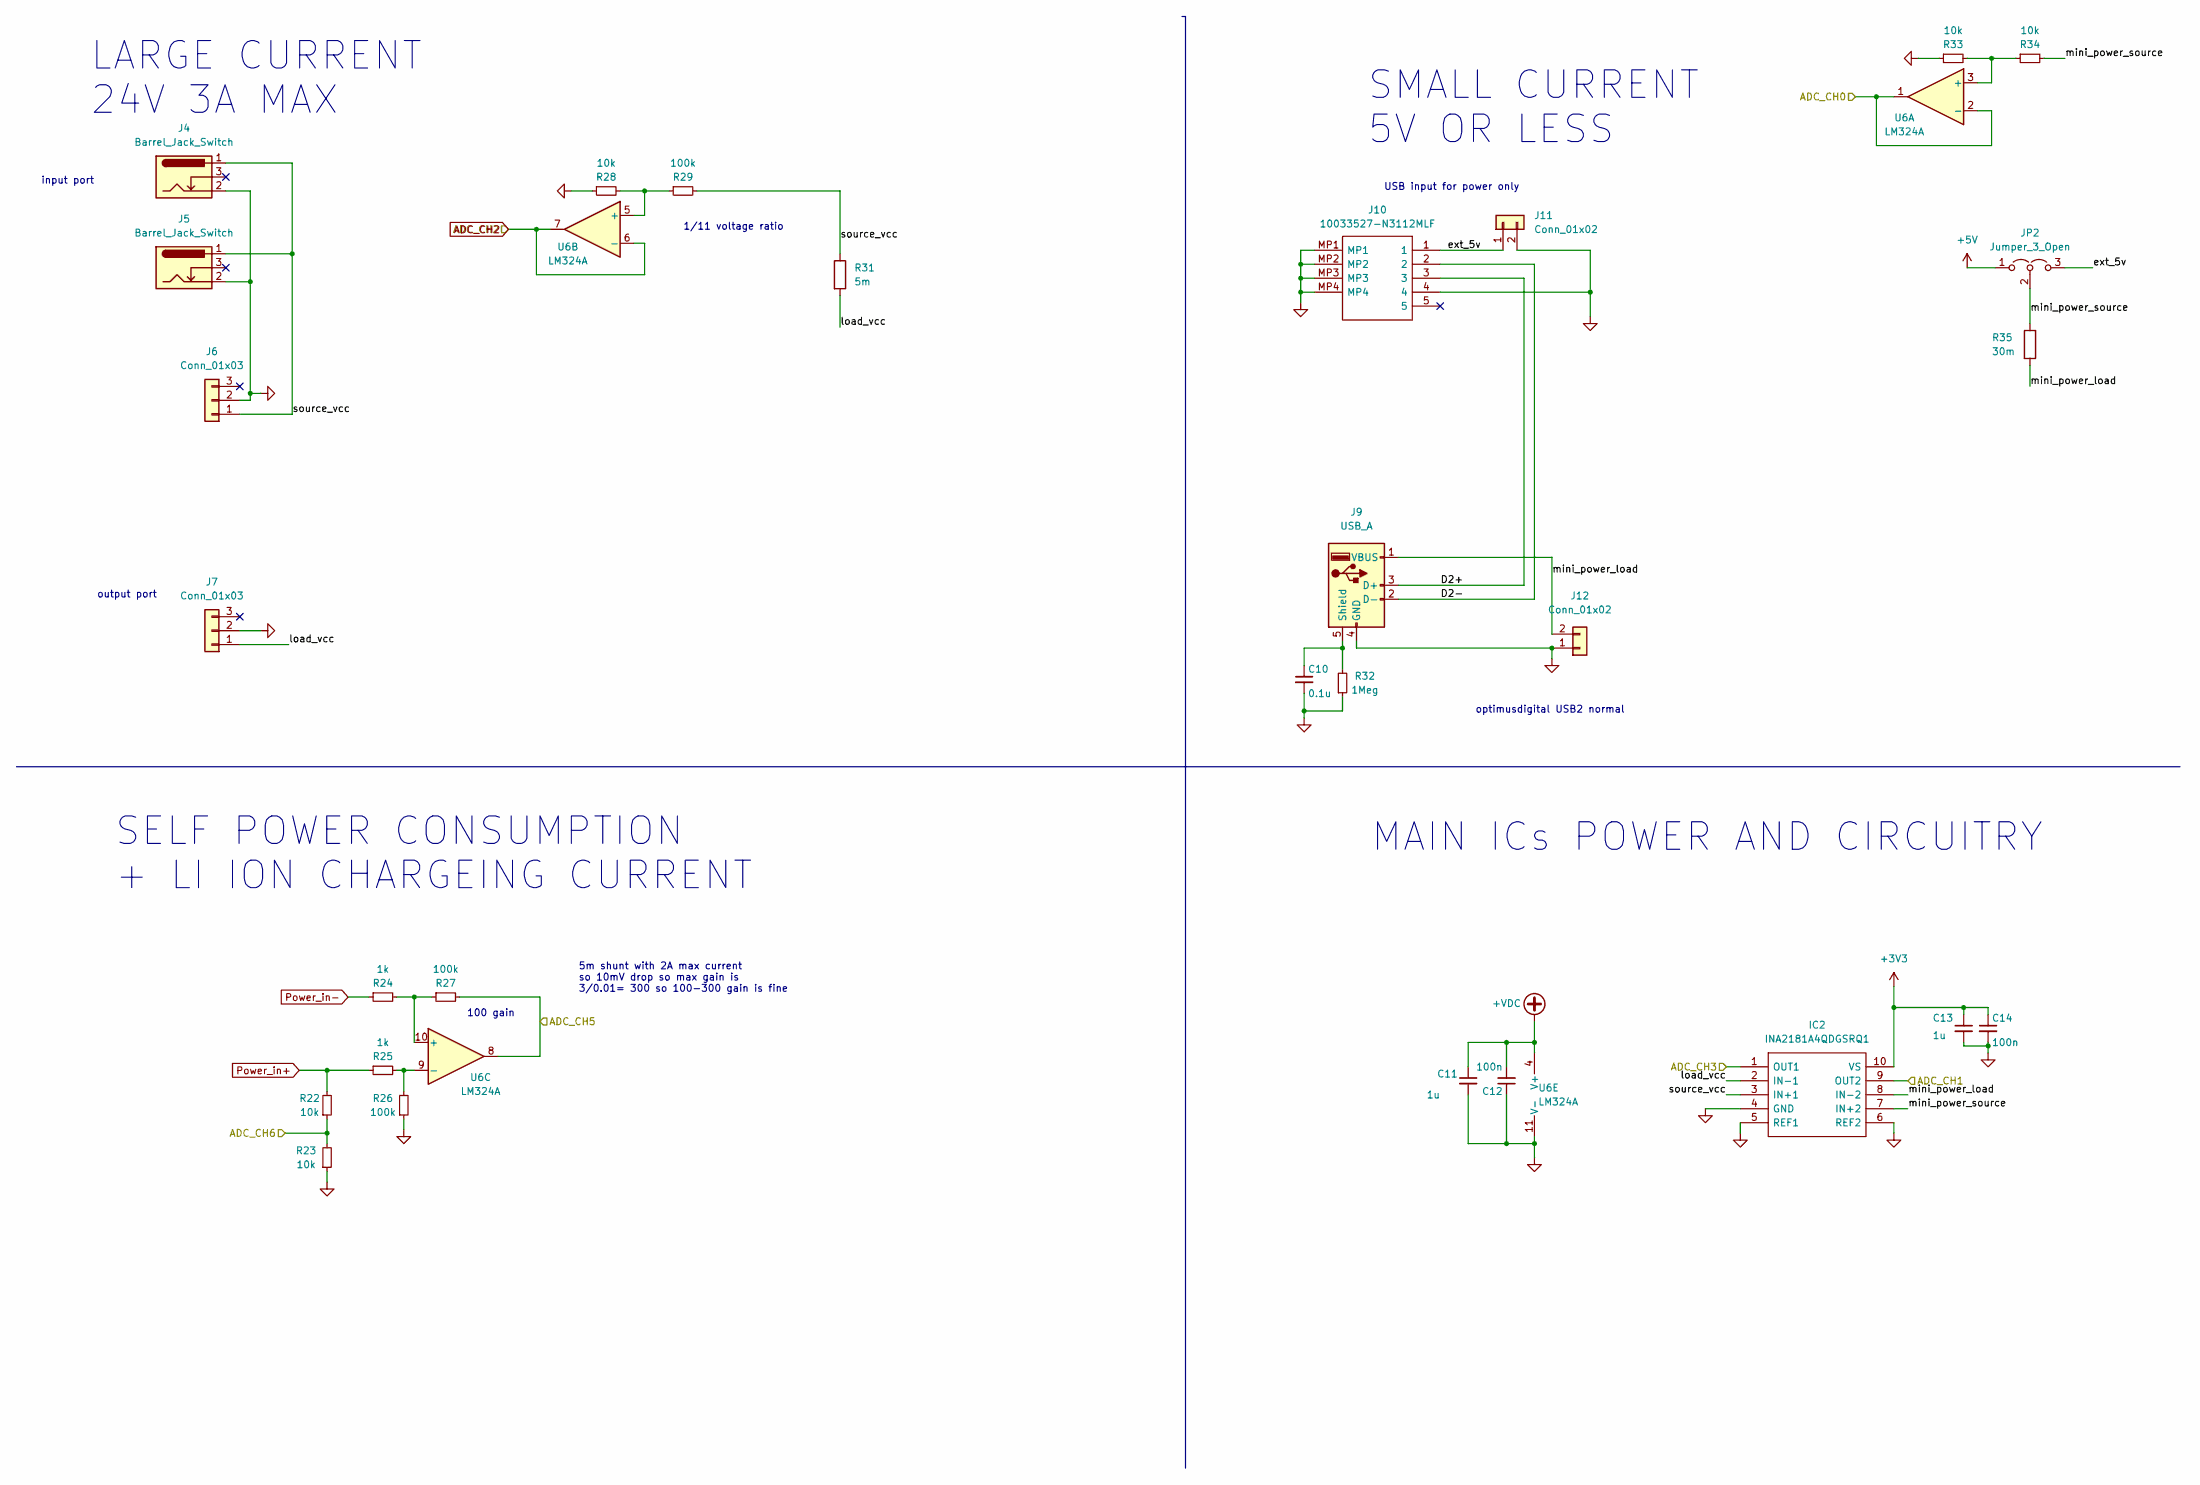
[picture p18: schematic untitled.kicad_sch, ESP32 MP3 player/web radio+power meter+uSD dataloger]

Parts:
C10: 0.1u; C_0603_1608Metric_Pad1.08x0.95mm_HandSolder
C11, C13: 1u; C_0603_1608Metric_Pad1.08x0.95mm_HandSolder
C12, C14: 100n; C_0603_1608Metric_Pad1.08x0.95mm_HandSolder
IC2: INA2181A4QDGSRQ1; SOP50P490X110-10N; Mouser Part Number 595-INA2181A4QDGSRQ1
J4: Barrel_Jack_Switch; DC plug jack 5.5-2.5mm
J5: Barrel_Jack_Switch; BarrelJack_Wuerth_6941xx301002
J6, J7: Conn_01x03; SCREWTERMINAL-5MM-3
J9: USB_A; USB_A_Molex_67643_Horizontal
J10: 10033527-N3112MLF; 10033527N3112MLF; Mouser Part Number 649-10033527N3112MLF
J11, J12: Conn_01x02; TestPoint_2Pads_Pitch5.08mm_Drill1.3mm
JP2: Jumper_3_Open; PinHeader_1x03_P2.54mm_Vertical
R22, R23, R28, R33, R34: 10k; R_0603_1608Metric_Pad0.98x0.95mm_HandSolder
R24, R25: 1k; R_0603_1608Metric_Pad0.98x0.95mm_HandSolder
R26, R27, R29: 100k; R_0603_1608Metric_Pad0.98x0.95mm_HandSolder
R31: 5m; R_0612_1632Metric_Pad1.18x3.40mm_HandSolder
R32: 1Meg; R_0603_1608Metric_Pad0.98x0.95mm_HandSolder
R35: 30m; R_0402_1005Metric_Pad0.72x0.64mm_HandSolder
U6: LM324A; SOIC-14_3.9x8.7mm_P1.27mm

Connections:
+5V: JP2.1 (A); also elsewhere on the board
+VDC: C11.1, C12.2, U6.4 (V+); also elsewhere on the board
/POWER_MEASUREMENTS/D2+: J9.3 (D+), J10.3
/POWER_MEASUREMENTS/D2-: J9.2 (D-), J10.2
/POWER_MEASUREMENTS/ext_5v: J10.1, J11.1, JP2.3 (B)
/POWER_MEASUREMENTS/load_vcc: IC2.2 (IN-1), J7.1, R31.2
/POWER_MEASUREMENTS/mini_power_load: IC2.8 (IN-2), J9.1 (VBUS), J12.2, R35.1
/POWER_MEASUREMENTS/mini_power_source: IC2.7 (IN+2), JP2.2 (C), R34.2, R35.2
/POWER_MEASUREMENTS/source_vcc: IC2.3 (IN+1), J4.1, J5.1, J6.1, R29.2, R31.1
ADC_CH0: U6.1, U6.2 (-); also elsewhere on the board
ADC_CH1: IC2.9 (OUT2); also elsewhere on the board
ADC_CH2: U6.6 (-), U6.7; also elsewhere on the board
ADC_CH3: IC2.1 (OUT1); also elsewhere on the board
ADC_CH5: R27.2, U6.8; also elsewhere on the board
ADC_CH6: R22.1, R23.2; also elsewhere on the board
GND: C10.2, C11.2, C12.1, C13.2, C14.2, IC2.4 (GND), IC2.5 (REF1), IC2.6 (REF2), J4.2, J5.2, J6.2, J7.2, J9.4 (GND), J10.4, J10.MP1, J10.MP2, J10.MP3, J10.MP4, J11.2, J12.1, R23.1, R26.1, R28.1, R32.1, R33.1, U6.11 (V-); also elsewhere on the board
unnamed: C10.1, J9.5 (Shield), R32.2
unnamed: R24.2, R27.1, U6.10 (+)
unnamed: R25.2, R26.2, U6.9 (-)
unnamed: R28.2, R29.1, U6.5 (+)
unnamed: R33.2, R34.1, U6.3 (+)
Power_in+: R22.2, R25.1; also elsewhere on the board
Power_in-: R24.1; also elsewhere on the board

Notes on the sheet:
USB input for power only
100 gain
SMALL CURRENT 5V OR LESS
1/11 voltage ratio
input port
5m shunt with 2A max current so 10mV drop so max gain is 3/0.01= 300 so 100-300 gain is fine
SELF POWER CONSUMPTION + LI ION CHARGEING CURRENT
output port
LARGE CURRENT 24V 3A MAX
MAIN ICs POWER AND CIRCUITRY
optimusdigital USB2 normal

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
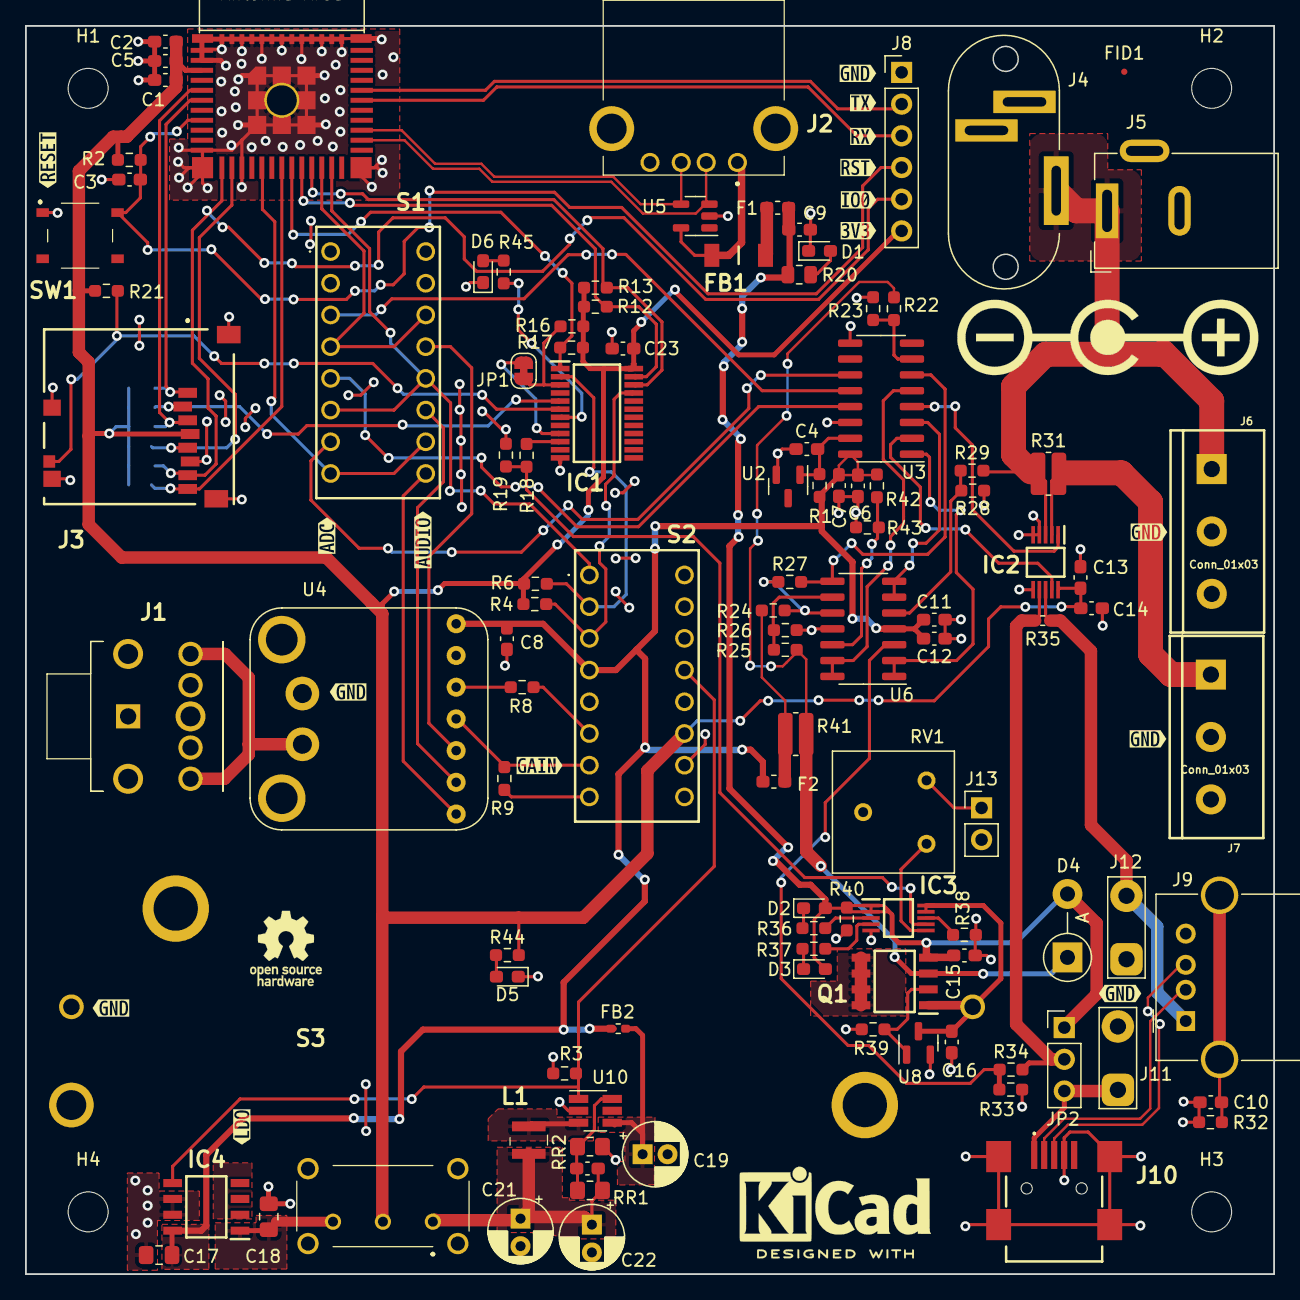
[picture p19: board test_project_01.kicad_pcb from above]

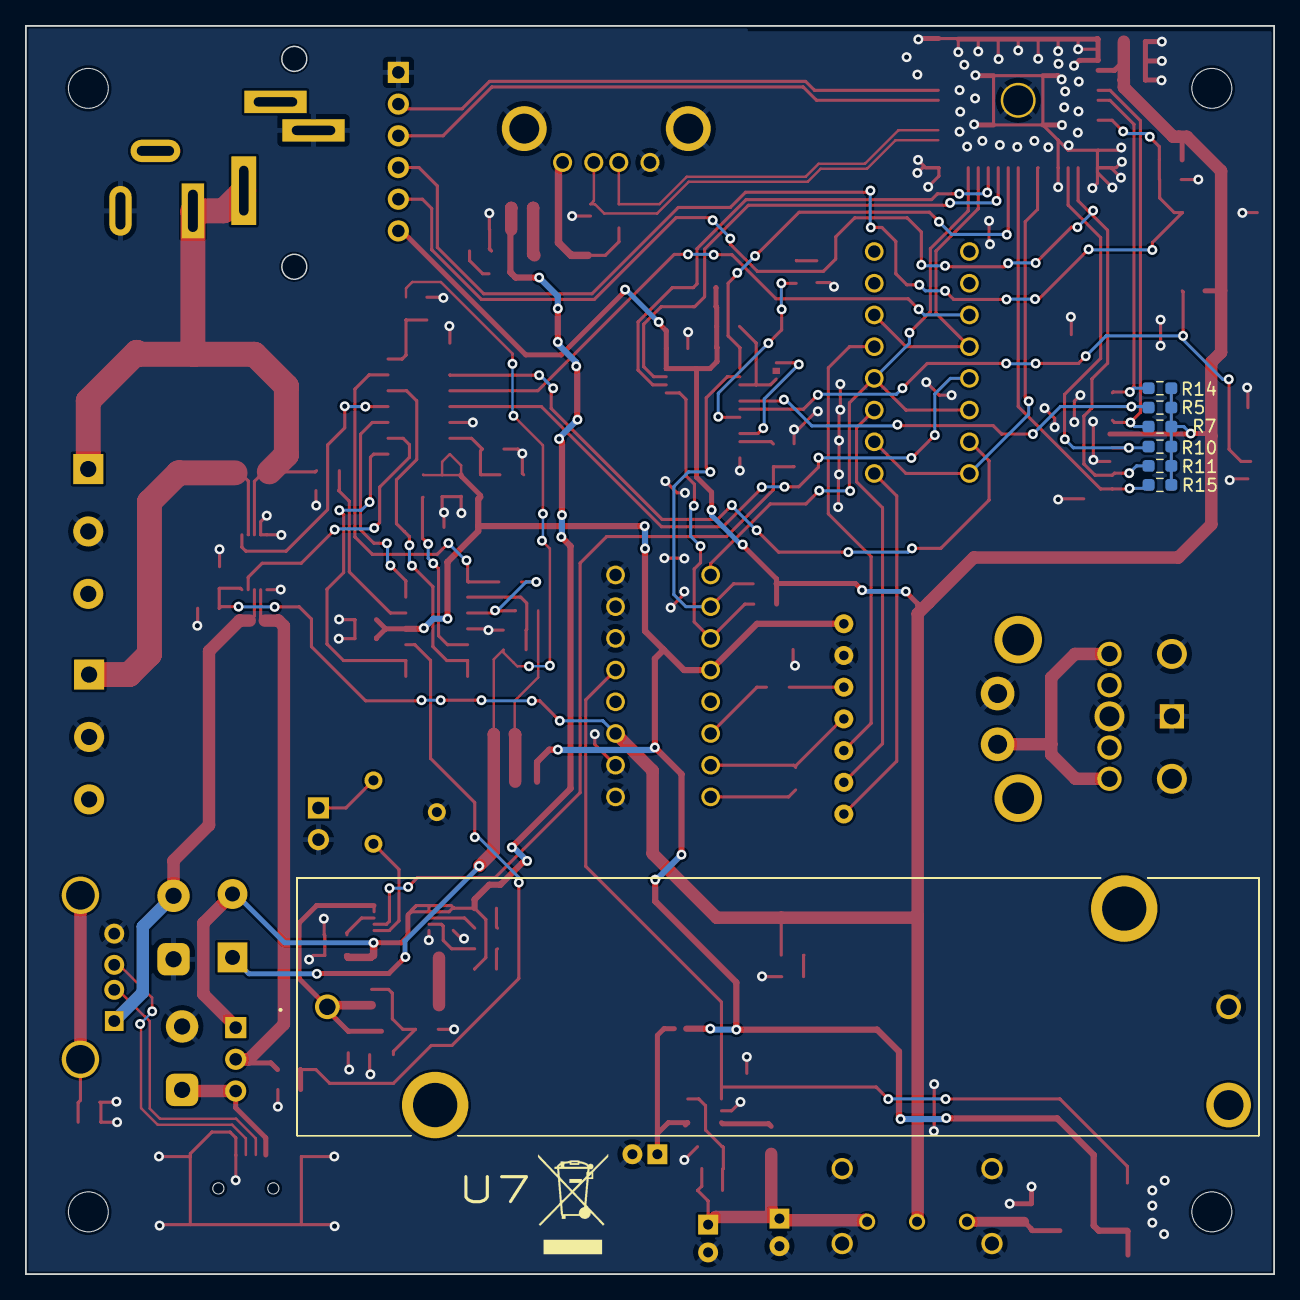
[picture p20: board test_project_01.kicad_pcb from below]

Board: 2 copper layers, 100.0 x 100.0 mm, 139 parts (8 on the bottom side), 84 nets.

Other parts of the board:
kibuzzard-62BCC6A1, kibuzzard-62BCC6A1#2: G***; kibuzzard-62BCC6A1
kibuzzard-62BCC6D2, kibuzzard-62BCC6D2#2, kibuzzard-62BCC6D2#3: G***; kibuzzard-62BCC6D2
kibuzzard-62BCC6DA: G***; kibuzzard-62BCC6DA
kibuzzard-62BCC6E5: G***; kibuzzard-62BCC6E5
kibuzzard-62BCC6EE: G***; kibuzzard-62BCC6EE
kibuzzard-62BCC6FB: G***; kibuzzard-62BCC6FB
kibuzzard-62BCC557: G***; kibuzzard-62BCC557
kibuzzard-62BCC581: G***; kibuzzard-62BCC581
kibuzzard-62BCC683: G***; kibuzzard-62BCC683
kibuzzard-62BCC715: G***; kibuzzard-62BCC715
kibuzzard-62BCCB31: G***; kibuzzard-62BCCB31
kibuzzard-62BCCBA4: G***; kibuzzard-62BCCBA4
kibuzzard-62BCCBB0: G***; kibuzzard-62BCCBB0
